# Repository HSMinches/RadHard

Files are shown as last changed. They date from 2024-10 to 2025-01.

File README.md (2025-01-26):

# RadHard
Radiation Hardened Voltage Regulation

Setup inicial de testes em um regulador compensado contra radiação e drifts de temperatura.

O tema central deste trabalho é o desenvolvimento de "Reguladores de tensão lineares para aplicações de baixo ruído em ambientes hostis", uma questão alinhada aos desafios enfrentados em setores críticos, como o aeroespacial e nuclear. Nesses contextos, os sistemas eletrônicos estão frequentemente sujeitos a variações extremas de temperatura e altos níveis de radiação, fatores que podem causar falhas graves, como Efeitos de Evento Único (SEE) e Danos Acumulados de Radiação (TID). Essas condições afetam diretamente o desempenho e a confiabilidade dos circuitos eletrônicos, especialmente em aplicações que exigem alta precisão e baixo ruído.

A escolha pelos reguladores de tensão lineares se justifica por sua capacidade de fornecer uma tensão de saída estável e limpa, essencial para circuitos sensíveis que necessitam de baixo ruído. Embora esses reguladores possam ser menos eficientes do que os modelos chaveados, sua baixa emissão de ruído os torna a opção mais adequada para sistemas de instrumentação e outros dispositivos que requerem alta estabilidade e precisão.

O objetivo deste projeto é desenvolver um regulador linear discreto, capaz de operar de forma eficiente em meio a grandes variações de temperatura e consideráveis níveis de exposição à radiação, evitando que essas condições provoquem alterações na tensão de saída, problema comum em ambientes hostis.

A imagem abaixo é referente a placa principal de regulação de tensão.



Data Flow Diagram Whiteboard in Dark Yellow Light Yellow Black Monochromatic Style(1)

Explicação dos blocos do diagrama: 

* Controle: bloco responsável pelo controle de toda a fonte, controlando a tensão e a corrente e pode desligar a fonte caso condições adversas aconteçam. Ele está localizado no meio da placa. 
* Temperatura: responsável pela medição de temperatura interna da placa. Tem ligação direta ao controle. A direita do bloco de radiação.
* Radiação: responsável pela medição de radiação incidida sobre o dispositivo. Se encontra no canto esquerdo inferior. 
* Referência: como o próprio nome já diz, é uma referência sobre a tensão estável do circuito. Canto superior esquerdo da placa.
* Proteção: protege contra sobretensão, transientes indesejados, proteção contra polaridade reversa e surtos de corrente. Está distribuído por toda a placa.
* Elemento de potência: São os elementos responsáveis por regular a tensão e suportar a maior carga de potência indesejado. Localizado na parte de trás da placa.



O bloco de controle é composto pelos componentes localizados no centro da placa, possui OP-AMPS e resistores de alta precisão e baixo drift térmico. 

# TESTES REALIZADOS

Após realizar o assembly dos componentes na PCB desenvolvida, foram realizados os seguintes testes para comprovar resultados iniciais utilizando o seguinte setup de testes:

setup1

O setup consiste de uma fonte auxiliar para gerar a alimentação negativa do circuito, um multímetro de 7 1/2 dígitos controlado por GPIB, uma fonte de sistema para alimentar a entrada da placa e a tensão auxiliar positiva da placa, um ADALM2000 para capturar dados de teste do LTPA (" Linear Technology Power Analyzer "), e uma probe de corrente que atua também como uma carga ativa na saída do circuito.  

Os seguintes resultados foram obtidos:

* Estabilidade de tensão:

Utilizando o multímetro de precisão em ambiente com temperatura controlada, foram adquiridas amostras durante várias horas em 2 níveis de tensão diferentes para avaliar a estabilidade do sistema. Como as figuras abaixo mostram:

5VREF_FILTERED

7VREF

Podendo obter bons resultados e com boa estabilidade em geral com os resultados medidos. 

* Transiente de cargas e ripple de regulação:

Foi utilizado o ADALM2000 e o LTPA em conjunto com a probe de corrente para gerar uma corrente de carga na saída do DUT, analisando assim a resposta de saída do sistema.

LTPA

Como demonstrado, existe um ripple extremamente baixo, mesmo com um transiente de carga rápido. Para cargas prolongadas, será necessário desenvolver uma solução térmica apropriada para o DUT.

* Teste de sobretemperatura:

Para evitar o stress dos componentes da placa, foi utilizado um soprador térmico em 100C para levar o sistema a falha de sobretemperatura, como este utiliza um disparador Schmitt, o sistema volta a funcionar automáticamente após a temperatura estabilizar em um nível aceitável novamente. No caso de falha, o sistema sai do indicador verde para o indicador laranja. 

https://github.com/user-attachments/assets/5670507f-7ce3-459a-abeb-b3ff87b2f2d7

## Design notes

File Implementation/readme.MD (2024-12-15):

INTRODUÇÃO                      
  O nosso projeto visa desenvolver e demonstrar o funcionamento de um regulador de tensão e corrente projetado para operar em ambientes extremos, com variações de temperaturas e exposição à radiação. O projeto é voltado para aplicações em setores como aeroespacial, indústria nuclear e setor militar, onde a robustez e a confiabilidade são fundamentais. 

OBJETIVO                  
  O principal objetivo do projeto é desenvolver um regulador de tensão e corrente capaz de:        
● Operar em temperaturas que variam de 0°C a 60°C ou mais.          
● Resistir a doses elevadas de radiação ionizante sem comprometer a funcionalidade.         
● Fornecer tensões e correntes estáveis em condições adversas.                   
● Garantir durabilidade e confiabilidade mesmo em ciclos térmicos prolongados e sob exposição à radiação.         
● A regulação de tensão e corrente se dá por malhas de feedback analógico. Sua tensão máxima de saída gira em torno de 14V, já a máxima corrente de saída, podemos afirmar que gira em torno de 1A.

MATERIAIS              
  A seleção dos materiais foi baseada em técnicas de compensação térmica e técnicas de design contra falhas induzidas por radiação, levando como base desempenho por custo benefício. Ademais todos os componentes deste projeto foram adquiridos de forma gratuita. Contudo se fossemos fazer uma estimativa de custo para esse projeto, o valor total estaria próximo de $2000 USD.

TESTES FUTUROS               
  O protótipo será submetido a uma série de testes para validar seu desempenho e durabilidade:    
● HASS (Highly Accelerated Stress Screening): O regulador será colocado em câmaras climáticas para avaliar seu funcionamento em condições de calor e frio.     
● Exposição à Radiação: Ensaios com feixes de íons pesados e fontes de radiação irão simular condições espaciais e ambientes nucleares.       
● HALT (Highly Accelerated Life Test) : O dispositivo irá ser submetido a ciclos repetidos de aquecimento e resfriamento para verificar sua resistência à fadiga térmica.   

CONCLUSÃO                  
      O regulador desenvolvido tende a ter desempenho satisfatório, operando de forma aceitável em variações de temperaturas e sob exposição a doses de radiação. Com base em especificações de componentes obtidas em bancos de dados, o dispositivo estaria apto para aplicações em ambientes adversos, como indústria aeroespacial, indústria nuclear e determinados usos militares. O sucesso deste projeto reforça a viabilidade do uso de componentes COTS (Commercial-Off-The-Shelf) e estratégias de design tolerantes a condições adversas.

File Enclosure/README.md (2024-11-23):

A case que irá envolver a placa foi desenvolvida utilizando o software Inventor e será fabricada em alumínio, um material conhecido por sua resistência e leveza. O principal objetivo dessa case é fornecer uma proteção robusta para a placa e seus componentes, evitando danos mecânicos, poeira e outras interferências externas que poderiam comprometer seu funcionamento. Além disso, o uso de alumínio contribui para a dissipação de calor, ajudando a manter os componentes em uma temperatura ideal e prolongando a vida útil do equipamento.

Montagem1

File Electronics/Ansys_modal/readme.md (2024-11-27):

Análise modal até a oitava ordem : 

ModalAnalysis

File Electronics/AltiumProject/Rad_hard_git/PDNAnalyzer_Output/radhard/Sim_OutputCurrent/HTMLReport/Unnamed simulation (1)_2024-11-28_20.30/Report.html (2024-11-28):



PDN Analyzer Results Report for
radhard

PDN Analyzer Version: 2.0.42.524
Report Time / Date: 11/28/2024 8:30:09 PM
Project Name: radhard
Project Path: C:\Users\Public\Documents\Altium\Projects\RAD_GIT\RadHard\Electronics\AltiumProject\Rad_hard_git\radhard.PcbDoc
PCB Design Name: radhard.PcbDoc
PDN Analyzer Configuration File: C:\Users\Public\Documents\Altium\Projects\RAD_GIT\RadHard\Electronics\AltiumProject\Rad_hard_git\PDNAnalyzer_Output\radhard\Unnamed simulation (1)\HTMLReport\Unnamed simulation (1)_2024-11-28_20.30\Unnamed simulation (1).pdna

Design Stackup

Layer Name | Layer Name | Material | Thickness (mm) | Dielectric Material | Dielectric Constant | Pullback (mm) | Orientation
Top Overlay | Overlay | | | | | | Top
Top Solder | Solder Mask | Surface Material | 0.0254 | SM-001 | 4 | | Top
Top Layer | Signal | Copper | 0.035 | | | | Top
Dielectric 1 | Dielectric | Prepreg | 0.07112 | PP-006 | 4.1
Dielectric 2 | Dielectric | Prepreg | 0.07112 | PP-006 | 4.1
Int1 (GND) | Internal | Copper | 0.035 | | | 0.508
Dielectric 3 | Dielectric | Core | 0.4572 | Core-035 | 4.7
Int2 (Sign) | Signal | Copper | 0.035
Dielectric 4 | Dielectric | Prepreg | 0.07112 | PP-006 | 4.1
Dielectric 5 | Dielectric | Prepreg | 0.07112 | PP-006 | 4.1
Int3 (Sign) | Signal | Copper | 0.035
Dielectric 6 | Dielectric | Core | 0.4572 | Core-035 | 4.7
Int4 (PWR) | Internal | Copper | 0.035 | | | 0.508
Dielectric 7 | Dielectric | Prepreg | 0.07112 | PP-006 | 4.1
Dielectric 8 | Dielectric | Prepreg | 0.07112 | PP-006 | 4.1
Bottom Layer | Signal | Copper | 0.035 | | | | Bottom
Bottom Solder | Solder Mask | Surface Material | 0.0254 | SM-001 | 4 | | Bottom
Bottom Overlay | Overlay | | | | | | Bottom

Artwork by Layer

Layer: Top Layer
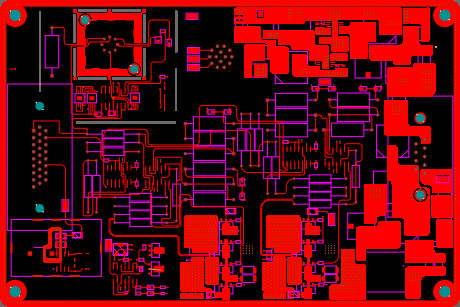
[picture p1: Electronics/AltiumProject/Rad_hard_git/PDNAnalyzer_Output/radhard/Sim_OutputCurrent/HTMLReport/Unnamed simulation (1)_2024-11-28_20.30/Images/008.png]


Layer: Int1 (GND)
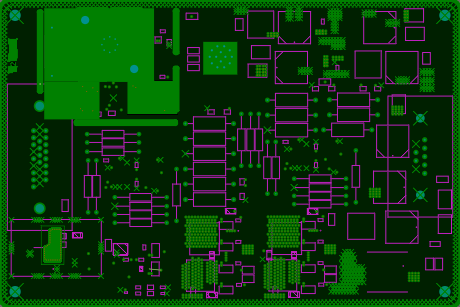
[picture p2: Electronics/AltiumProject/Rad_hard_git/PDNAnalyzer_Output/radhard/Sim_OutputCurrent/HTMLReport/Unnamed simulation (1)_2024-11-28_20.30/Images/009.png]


Layer: Int2 (Sign)
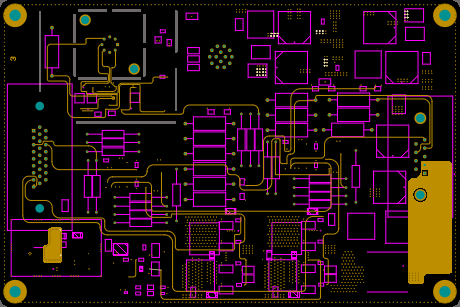
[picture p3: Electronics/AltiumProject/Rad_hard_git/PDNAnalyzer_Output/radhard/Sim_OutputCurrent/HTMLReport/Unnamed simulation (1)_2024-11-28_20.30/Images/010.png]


Layer: Bottom Layer
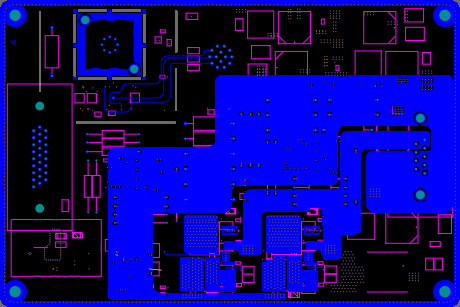
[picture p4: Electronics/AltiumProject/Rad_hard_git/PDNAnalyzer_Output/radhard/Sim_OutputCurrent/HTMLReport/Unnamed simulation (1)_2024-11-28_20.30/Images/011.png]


PDN Analizer Global Settings

Parameter | Value
Metal conductivity | 47M S/m
Metal base temperature | 3E+01 °C
Metal work temperature | 3E+01 °C
Metal base conductivity | 47M S/m
Metal temperature coefficient | 4E+02m %/°C
Conductor Max Current Density for Surfase Layers | 0 A/mm^2
Conductor Max Current Density for Internal Layers | 0 A/mm^2
Via wall thickness | 17.78 μm
Max Via Current Density | 0 A/mm^2

System-Level Power Network Results

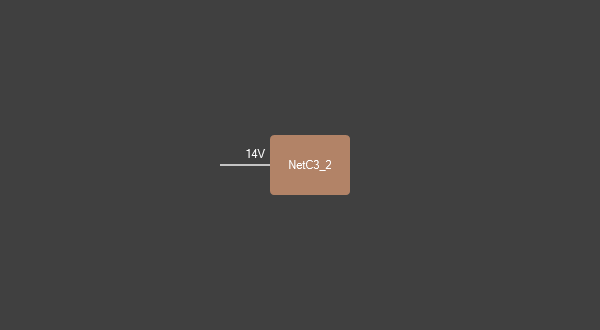
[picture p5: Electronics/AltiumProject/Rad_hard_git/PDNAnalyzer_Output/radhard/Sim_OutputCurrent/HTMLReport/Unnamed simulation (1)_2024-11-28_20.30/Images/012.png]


Simulation Pass/Fail Overall: PASS
NetC3_2 PASS

Total Power Consumption: 56 Watts

Figure <1>: Probe 003 Screenshot

13.97 V on Layer: BOTTOM_LAYER Net: NETC3_2 Coordinates: 163.060 : 80.315

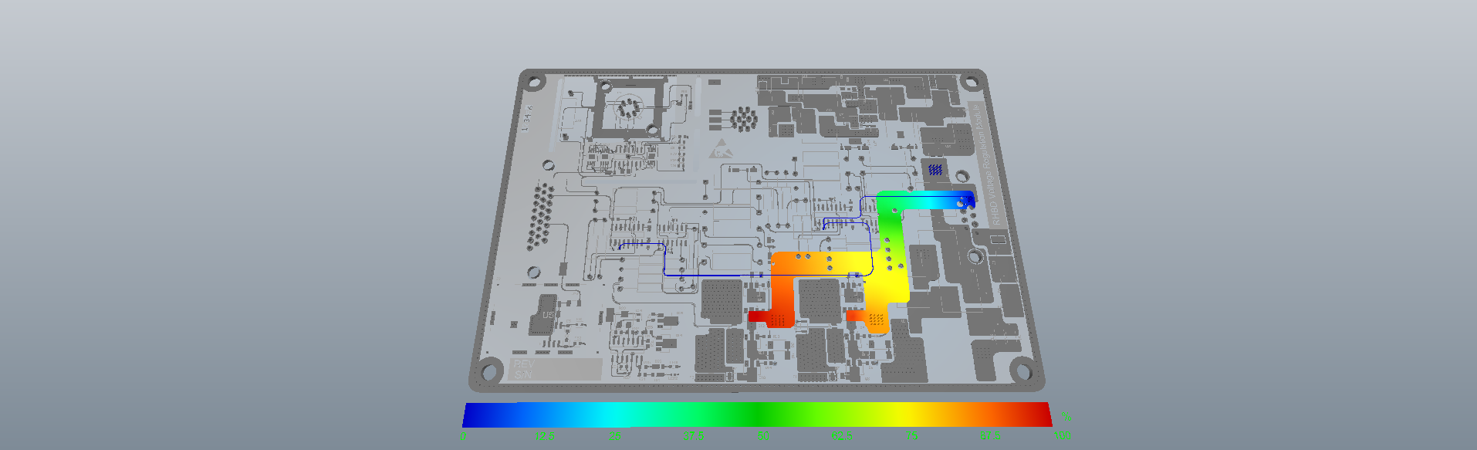
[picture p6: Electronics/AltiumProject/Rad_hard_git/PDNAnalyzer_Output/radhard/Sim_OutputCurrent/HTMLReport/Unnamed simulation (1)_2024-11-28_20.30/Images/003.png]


Figure <2>: Probe 002 Screenshot

13.97 V on Layer: BOTTOM_LAYER Net: NETC3_2 Coordinates: 163.060 : 80.315

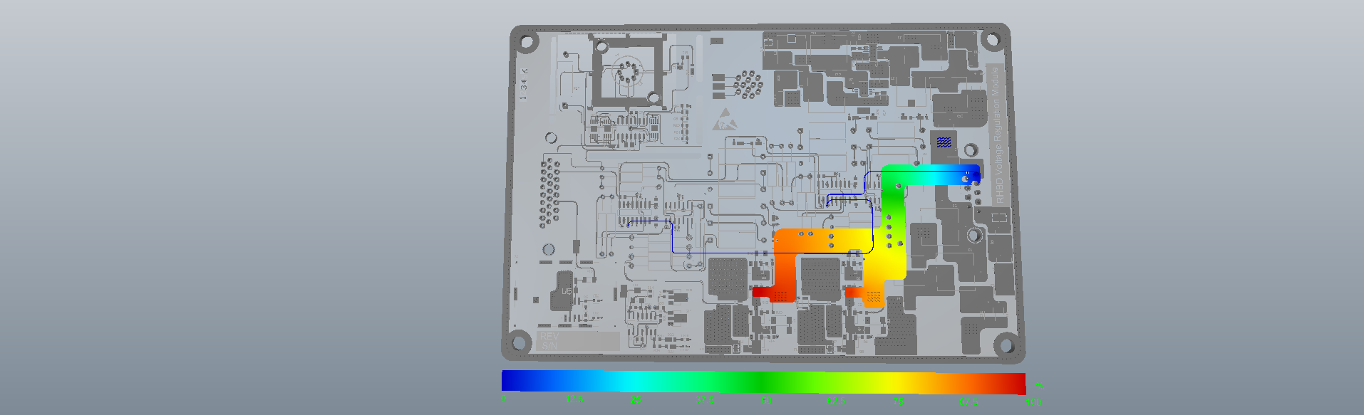
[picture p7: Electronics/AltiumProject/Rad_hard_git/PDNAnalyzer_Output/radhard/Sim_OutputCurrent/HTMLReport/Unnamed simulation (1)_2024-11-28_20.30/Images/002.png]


Figure <3>: Screenshot 004

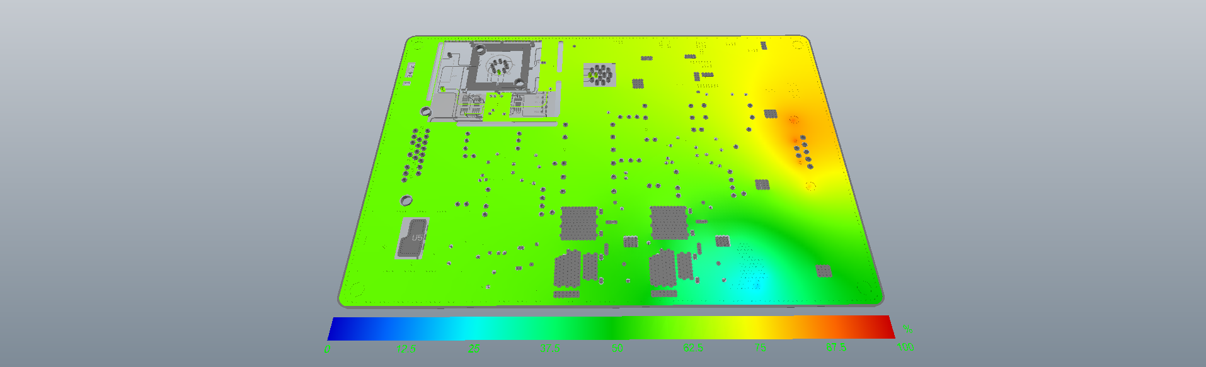
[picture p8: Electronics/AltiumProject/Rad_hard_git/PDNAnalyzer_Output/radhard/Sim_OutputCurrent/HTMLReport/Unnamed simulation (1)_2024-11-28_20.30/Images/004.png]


Figure <4>: Screenshot 005

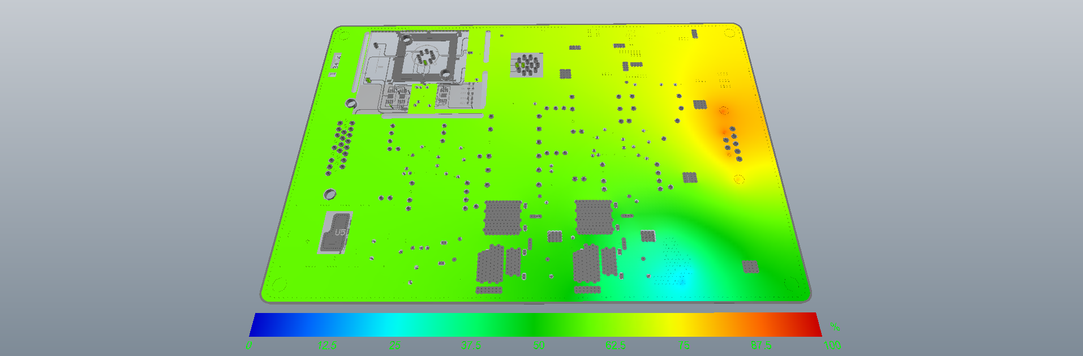
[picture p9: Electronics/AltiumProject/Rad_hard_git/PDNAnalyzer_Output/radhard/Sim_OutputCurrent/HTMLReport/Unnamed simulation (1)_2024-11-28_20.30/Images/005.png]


Figure <5>: Screenshot 006

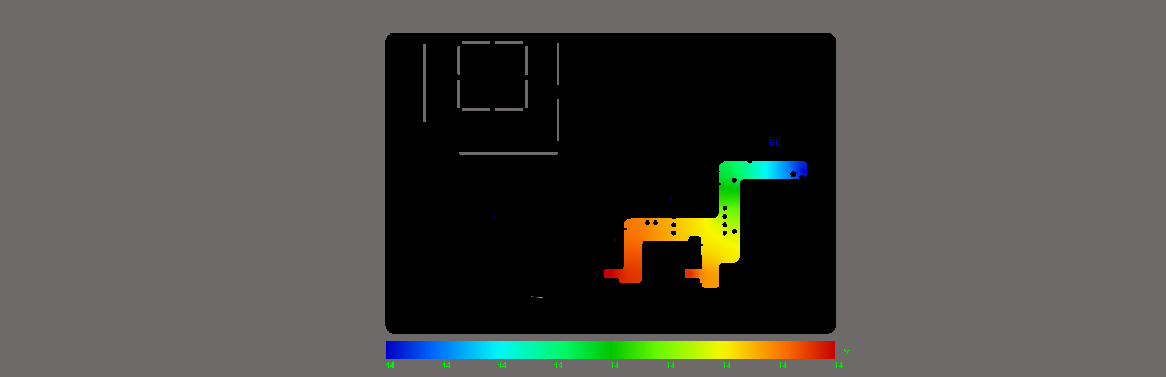
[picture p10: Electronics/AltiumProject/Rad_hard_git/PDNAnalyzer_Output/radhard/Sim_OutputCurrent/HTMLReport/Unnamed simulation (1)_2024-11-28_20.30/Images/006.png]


Figure <6>: Screenshot 007

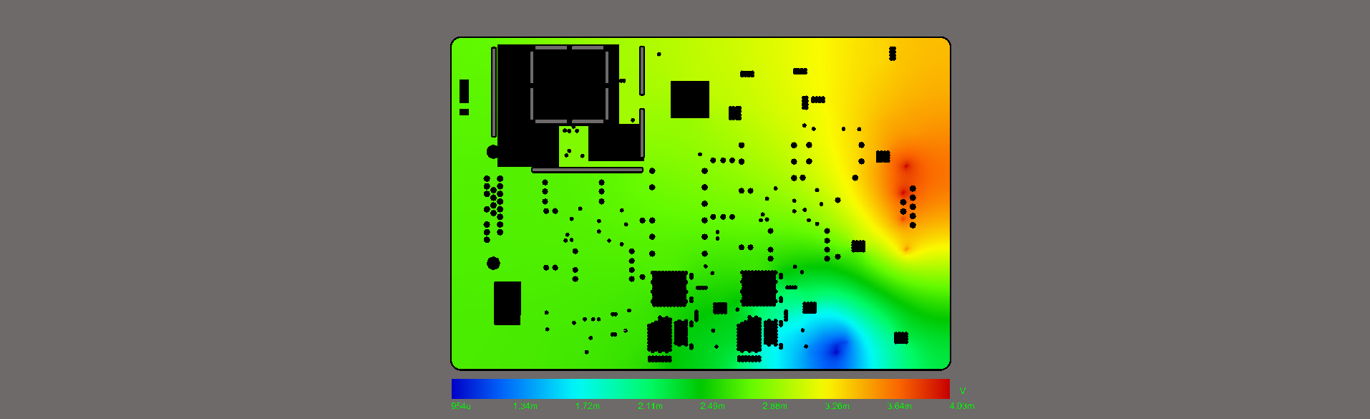
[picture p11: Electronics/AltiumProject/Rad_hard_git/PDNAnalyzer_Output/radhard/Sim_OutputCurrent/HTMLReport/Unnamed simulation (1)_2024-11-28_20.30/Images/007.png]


Network NetC3_2 Details

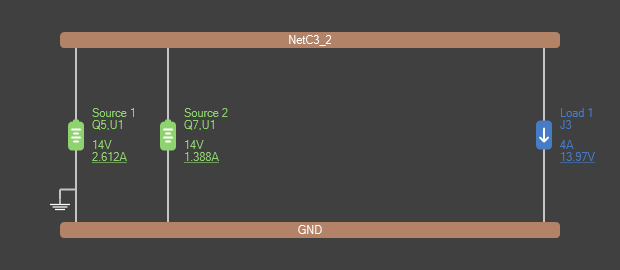
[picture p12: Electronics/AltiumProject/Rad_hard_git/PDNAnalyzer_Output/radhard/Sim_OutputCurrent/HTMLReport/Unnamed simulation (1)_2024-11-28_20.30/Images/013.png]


PDN Analysis Pass/Fail: PASS

Power Consumption for This Network: 56 Watts

Voltage Source Performance Summary:

ID | Source Type | Ref Des | Pass / Fail | Vout setting (V) | Actual Output Voltage (V) | Max Output Current (A) | Actual Output Current (A) | Margin (A) | Margin (%) | Max Pin Current | Highest Actual (A) | Margin (A) | Margin (%) | Max Power Dissipation (W) | Actual Power Dissipation (W) | Margin (W) | Margin (%)
Source 1 | Voltage Source | Q5, U1 | PASS | 14 | 13.997 | 0 | 2.6118 | ∞ | ∞ | 0 | 2.6118 | ∞ | ∞
Source 2 | Voltage Source | Q7, U1 | PASS | 14 | 13.999 | 0 | 1.3882 | ∞ | ∞ | 0 | 1.3882 | ∞ | ∞

Voltage Source Pin Voltage/Current Details:

ID | SourceType | Terminal | Ref Des | Pin | Max Pin Current (A) | Actual Pin Current (A) | Pass / Fail | Pin Voltage (V)
Source 1 | Voltage Source | Power | Q5 | 3 | 0 | 2.6118 | PASS | 13.997
Source 1 | Voltage Source | Ground | U1 | 4 | 0 | 2.6118 | PASS | 0
Source 2 | Voltage Source | Power | Q7 | 3 | 0 | 1.3882 | PASS | 13.999
Source 2 | Voltage Source | Ground | U1 | 4 | 0 | 1.3882 | PASS | 0

Load Performance Summary:

ID | Load Type | Ref Des | Pass / Fail | Load Value | Min Voltage (V) | Max Voltage (V) | Actual Voltage | Margin (V) | Margin (%) | Min Pwr Pin | Voltage (V) | Max Gnd Pin | Voltage (V) | Actual Current (A)
Load 1 | Current | J3 | PASS | 4A | 0 | 0 | 13.969 | 0 | ∞ | J3-5 | 13.973 | J3-9 | 4.5406m | 4

Load Pin Voltage/Current Details:

ID | Load Type | Terminal | Ref Des | Pin | Pin Voltage (V) | Pin Current (A)
Load 1 | Current | Power | J3 | 5 | 13.973 | 4
Load 1 | Current | Ground | J3 | 9 | 4.5406m | 991.65m
Load 1 | Current | Ground | J3 | 6 | 4.3348m | 996.8m
Load 1 | Current | Ground | J3 | SH2 | 4.1907m | 1.0004
Load 1 | Current | Ground | J3 | SH1 | 3.7606m | 1.0112

Component Definition Summary:

ID | Ref Des | Type | In+ Pins | In- Pins | Out+ Pins | Out- Pins | S+ | S- | Vout (V) | Efficiency (%) | Ibias (A) | Resistance | Load Current (A) | Vmin | Vmax | Iout max (A) | PD max (W) | Pin Current max (A)
Source 1 | Q5, U1 | Voltage Source | | | Q5-3 | U1-4 | | | 14 | | | | | | | 0 | | 2.6118
Source 2 | Q7, U1 | Voltage Source | | | Q7-3 | U1-4 | | | 14 | | | | | | | 0 | | 1.3882
Load 1 | J3 | Current | J3-5 | J3-9,6,SH2,SH1 | | | | | | | | | 4 | 0 | 0

## Figure <7>: Screenshot 001

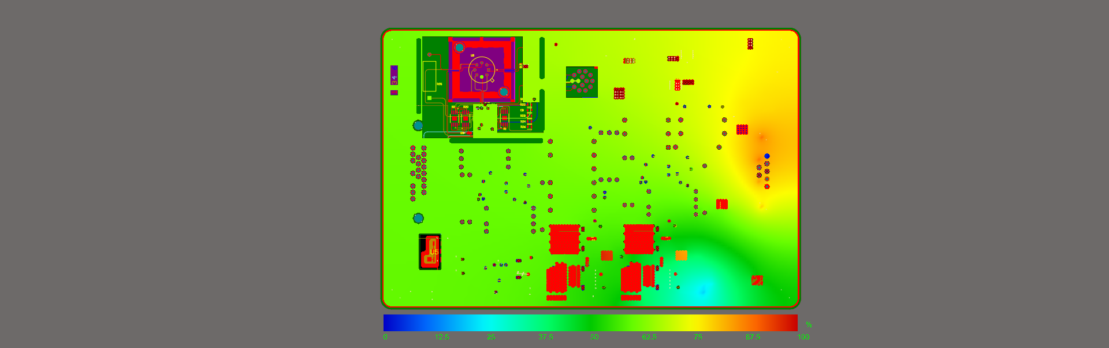
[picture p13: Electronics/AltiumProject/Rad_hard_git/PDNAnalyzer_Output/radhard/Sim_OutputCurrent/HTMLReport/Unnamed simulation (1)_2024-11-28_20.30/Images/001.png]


Network Simulation Messages Details

Type | Text
Info | Generated the settings file: C:\Users\Public\Documents\Altium\Projects\RAD_GIT\RadHard\Electronics\AltiumProject\Rad_hard_git\PDNAnalyzer_Output\radhard\Unnamed simulation (1)\radhard.py
Info | Load and analyze result for Unnamed simulation (1)
Info | No violations
Info | Analysis Complete Unnamed simulation (1)

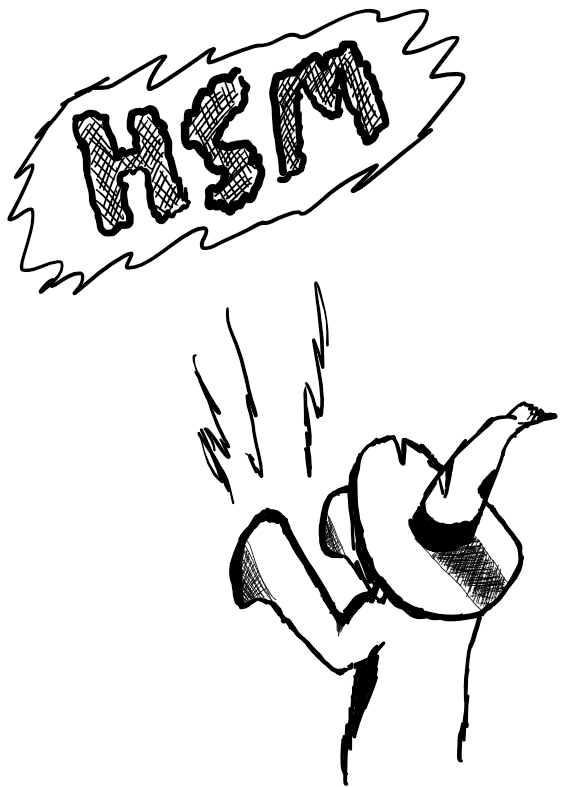
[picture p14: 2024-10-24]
Electronics/AltiumProject/Rad_hard_git/IMG/magesketch.bmp

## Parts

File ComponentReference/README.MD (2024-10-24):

Reference links for radiation tested components: 

-https://esarad.esa.int/
-https://radhome.gsfc.nasa.gov/radhome/RadDataBase/RadDataBase.html

Reference for significative test data interpretation:

-https://radhome.gsfc.nasa.gov/radhome/RadDataBase/RadDataBase.html

External design references: 

Josemary A.C. Gonçalves, Alessio Mangiarotti, Carmen C. Bueno,
Characterization of a thin photodiode as a routine dosimeter for low-dose radiation processing applications,
Radiation Physics and Chemistry,
Volume 198,
2022,
110200,
ISSN 0969-806X,

P. C. Adell and L. Z. Scheick, "Radiation Effects in Power Systems: A Review," in IEEE Transactions on Nuclear Science, vol. 60, no. 3, pp. 1929-1952, June 2013, doi: 10.1109/TNS.2013.2262235.
keywords: {Voltage control;Regulators;Topology;Radiation effects;Switches;Switching converters;Mathematical model;DC-DC converters;digital control;linear regulators;power systems;single event effects;total dose}

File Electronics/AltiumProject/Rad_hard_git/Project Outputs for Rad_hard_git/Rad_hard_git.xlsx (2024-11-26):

Comment | Description | Designator | Footprint | LibRef | Quantity
Component_1 |  | Amph | PCBComponent_1 | ACRK-16-01-G-T-B1-M-1 | 1
MAL214099801E3 | No Description Available | C1, C2, C3, C10, C11, C12, C13 | CAP_140CRH_1010_VIS | MAL214099801E3 | 7
12065A5R6DAT2A | CAP CER 5.6PF 50V C0G/NP0 1206 | C4 | CAPC3216X94N | 12065A5R6DAT2A | 1
CC0603KRX7R7BB105 | CAP CER 1UF 16V X7R 0603 | C5, C6, C14, C15, C16 | FP-CC0603-DA-MFG | CMP-03422-000924-1 | 5
06033C104KAT2A | General Purpose Ceramic Capacitor, 0603, 100nF, 10%, X7R, 15%, 25V | C7, C8 | FP-0603-L_1_6_0_15-W_0_81-MFG | CMP-2006-04157-2 | 2
VJ0805Y223KXXAC |  | C9 | CAPC2012X145N | VJ0805Y223KXXAC | 1
GRM31CR71E106KA12L | Chip Multilayer Ceramic Capacitors for General Purpose, 1206, 10uF, X7R, 15%, 10%, 25V | C17, C18, C19, C20 | FP-GRM31C-0_2-e0_3_0_8-MFG | CMP-06035-003589-1 | 4
CC0402KRX7R9BB104 | CAP CER 0.1UF 50V X7R 0402 | C21_Temperature_Enhanced_WB1, C21_Temperature_Enhanced_WB2, C22_Temperature_Enhanced_WB1, C22_Temperature_Enhanced_WB2, C23_Temperature_Enhanced_WB1, C23_Temperature_Enhanced_WB2 | FP-CC0402-MFG | CMP-03422-001010-1 | 6
PTVS12VP1UP,115 | Diode ESD (Uni-directional) | D1, D2, D5, D6, D11, D12, D17, D18 | PMEG3050EP115 | PTVS12VP1UP,115 | 8
YQ15RSM10SDTL1 | Schottky Diode | D3, D4, D7, D15, D16, D19, D20 | YQ15RSM10SDTL1 | YQ15RSM10SDTL1 | 7
VBPW34S | VBPW34SR Series 60 V 940 nm 50 mA 215 mW Surface Mount Silicon PIN Photodiode | D8 | XDCR_VBPW34S | VBPW34S | 1
RF05VYM1SFHTR | Diode | D9, D10, D21, D22, D23_Temperature_Enhanced_WB1, D23_Temperature_Enhanced_WB2, D24_Temperature_Enhanced_WB1, D24_Temperature_Enhanced_WB2, D25_Temperature_Enhanced_WB1, D25_Temperature_Enhanced_WB2, D26_Temperature_Enhanced_WB1, D26_Temperature_Enhanced_WB2 | RF05VYM1SFHTR | RF05VYM1SFHTR | 12
0483005.DR | Fuse | F1, F3 | FUSC3316X137N | 0483005.DR | 2
0483010.DR | Fuse | F2 | FUSC3316X137N | 0483010.DR | 1
MH1608-601Y | FERRITE BEAD 600 OHM 0603 1LN | FB1, FB2 | FP-MH1608-MFG | CMP-2000-06698-2 | 2
GUARD_RING |  | GR | Guard | Component_1 | 1
MDBRA26PEAN0 | Connector | J1 | MDBRA26PEAN0 | MDBRA26PEAN0 | 1
2118728-2 |  | J2 | TE_2118728-2 | 2118728-2 | 1
MDBRE09PE860 |  | J3 | AMPHENOL_MDBRE09PE860 | MDBRE09PE860 | 1
SER8052-402MEC | Inductor | L1, L2, L3 | SER8052402MEC | SER8052-402MEC | 3
SMLD12EN1WT86C | LED | LED1 | SMLD12EN1WT86C | SMLD12EN1WT86C | 1
SML-P11DTT86R | LED | LED2 | SML-P11(1X0.6) | SML-P11DTT86R | 1
UJ4SC075018B7S | MOSFET 750V/18mO,SICFET,G4,TO263-7 | Q1, Q6 | UJ4SC075018B7S | UJ4SC075018B7S | 2
2SD1834T100 | Transistor BJT NPN | Q2, Q3, Q4, Q8, Q9, Q10, Q11, Q12, Q14, Q15 | RJP020N06 | 2SD1834T100 | 10
IXTA6N100D2 | N-Channel 1000 V 6 A 2.2 Ohm SMT Depletion Mode Power Mosfet - D2PAK | Q5, Q7 | DPAK254P1524X483-3N | IXTA6N100D2 | 2
2SCR563F3TR | Transistor BJT NPN | Q13 | 2SAR542F3 | 2SCR563F3TR | 1
LT5400ACMS8E-3#PBF | 1k, 9k Ohm Â±15% 800mW Power Per Element Isolated Resistor Network/Array Â±25ppm/Â°C 8-TSSOP, 8-MSOP (0.118", 3.00mm Width) Exposed Pad | R1, R20 | SOP65P490X110-9N | LT5400ACMS8E-3#PBF | 2
LT5400BHMS8E-8#TRPBF | 1k, 9k Ohm Â±15% 800mW Power Per Element Isolated Resistor Network/Array Â±25ppm/Â°C 8-TSSOP, 8-MSOP (0.118", 3.00mm Width) Exposed Pad | R2 | SOP65P490X110-9N | LT5400BHMS8E-8#TRPBF | 1
WSLP0805R0100FEA |  | R3, R9 | RESC2013X58X38LL25T25 | CMP-2001-04321-1 | 2
ERA8AEB124V |  | R4, R7, R10, R11 | RESC3216X70X50LL20T25 | CMP-2003-04417-1 | 4
MCT06030C1001FP500 | Res Thin Film 0603 1K Ohm 1% 0.1W(1/10W) ?50ppm/C Molded SMD Automotive Medical T/R | R5, R6, R8, R12, R13, R14, R15, R17, R19, R21, R30, R34, R35, R50_Temperature_Enhanced_WB1, R50_Temperature_Enhanced_WB2, R53_Temperature_Enhanced_WB1, R53_Temperature_Enhanced_WB2, R54_Temperature_Enhanced_WB1, R54_Temperature_Enhanced_WB2, R55, R56 | RESC1508X55N | MCT06030C1001FP500 | 21
ERJ-8GEYJ241V |  | R16 | RESC3216X70X50NL05T20 | CMP-2003-00592-1 | 1
CRHP1206AF1G00FKET | No Description Available | R18 | RES_CRHP1206_VIS | CRHP1206AF1G00FKET | 1
MCT06030C1004FPW00 | RES SMD 100 OHM 1% 1/8W 0603 | R22, R23, R24, R26 | FP-MCT0603-MFG | CMP-02407-007592-1 | 4
UPF50B100RV | No Description Available | R25 | RES_UPF50B2K0V_TEC | UPF50B100RV | 1
0402WGF1000TCE | Resistor | R27 | RESC1005X40N | 0402WGF1000TCE | 1
TNPW0603120KBEEA |  | R28, R29 | RESC1508X55N | TNPW0603120KBEEA | 2
TNPW060310K0BEEA |  | R31 | RESC1609X55X30NL10T20 | CMP-2000-03691-1 | 1
PTS1206M2B1K00P100 | No Description Available | R32 | PTS 1206_VIS | PTS1206M2B1K00P100 | 1
3214W-1-502E | 3214 - 5-Turn Trimpot(R) Trimming Potentiometer, 5 KOhm, +/- 10%, 0.25 W, -65 to 150 degC, RoHS, Tape and Reel | R33 | BOUR-3214W_V | CMP-2000-05579-1 | 1
H810KBYA | Resistor | R36_Temperature_Enhanced_WB1, R36_Temperature_Enhanced_WB2, R37_Temperature_Enhanced_WB1, R37_Temperature_Enhanced_WB2 | RESAD1690W60L710D245 | H810KBYA | 4
H81M0BYA | Resistor | R38_Temperature_Enhanced_WB1, R38_Temperature_Enhanced_WB2, R39_Temperature_Enhanced_WB1, R39_Temperature_Enhanced_WB2 | RESAD1690W60L710D245 | H810KBYA | 4
H81K0BYA | Resistor | R40_Temperature_Enhanced_WB1, R40_Temperature_Enhanced_WB2, R45_Temperature_Enhanced_WB1, R45_Temperature_Enhanced_WB2, R46_Temperature_Enhanced_WB1, R46_Temperature_Enhanced_WB2, R49_Temperature_Enhanced_WB1, R49_Temperature_Enhanced_WB2, R51_Temperature_Enhanced_WB1, R51_Temperature_Enhanced_WB2, R52_Temperature_Enhanced_WB1, R52_Temperature_Enhanced_WB2 | RESAD1690W60L710D245 | H810KBYA | 12
UPF50B100KV | No Description Available | R41_Temperature_Enhanced_WB1, R41_Temperature_Enhanced_WB2, R42_Temperature_Enhanced_WB1, R42_Temperature_Enhanced_WB2, R43_Temperature_Enhanced_WB1, R43_Temperature_Enhanced_WB2, R44_Temperature_Enhanced_WB1, R44_Temperature_Enhanced_WB2, R47_Temperature_Enhanced_WB1, R47_Temperature_Enhanced_WB2, R48_Temperature_Enhanced_WB1, R48_Temperature_Enhanced_WB2 | RES_UPF50B2K0V_TEC | UPF50B100RV | 12
5019 |  | TP1, TP2, TP3, TP9, TP10, TP11, TP13, TP16, TP17 | KEYSTONE_5019 | 5019 | 9
CH4659-ALD | No Description Available | U1 | CH4659-ALD_COC | CH4659-ALD | 1
LT3045EMSE#TRPBF | IC REG LINEAR 0V 500MA 12MSOP | U2 | FP-MSE-12-05-08-1666-IPC_B | CMP-09138-000053-1 | 1
LTZ1000ACH#PBF | IC VREF SHUNT 7.2V TO5 | U3 | FP-H-8-05-08-1320-MFG | CMP-09137-000002-1 | 1
ADA4522-4ARZ-RL | IC OPAMP ZERO-DRIFT 4CIRC 14SOIC | U4, U6_Temperature_Enhanced_WB1, U6_Temperature_Enhanced_WB2, U9 | FP-R-14-IPC_C | CMP-09116-000280-1 | 4
ADA4530-1ARZ |  | U5 | SOIC127P600X175-8N | ADA4530-1ARZ | 1
LT3094EMSE#PBF | IC REG LIN NEG ADJ 500MA 12MSOP | U7 | FP-MSE-12-05-08-1666-MFG | CMP-09138-000010-1 | 1
ADG452BRZ | IC SWITCH QUAD SPST 16SOIC | U8_Temperature_Enhanced_WB1, U8_Temperature_Enhanced_WB2 | FP-R-16-IPC_B | CMP-09113-000001-1 | 2

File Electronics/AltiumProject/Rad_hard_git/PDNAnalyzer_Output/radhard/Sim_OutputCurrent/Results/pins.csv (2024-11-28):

refdes | pin | voltage | current
Q5 | 3 | 13.9974 | 2.61184
U1 | 4 | 0.0 | -4.0
Q7 | 3 | 13.9986 | 1.38816
J3 | 5 | 13.9731 | -4.0
J3 | 9 | 0.00454064 | 0.991651
J3 | 6 | 0.00433479 | 0.996798
J3 | SH2 | 0.00419073 | 1.0004
J3 | SH1 | 0.00376062 | 1.01115

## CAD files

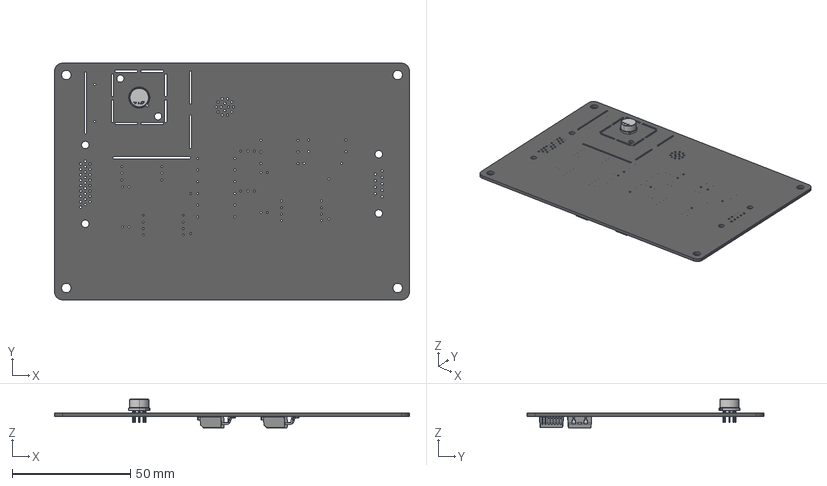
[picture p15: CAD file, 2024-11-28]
Electronics/AltiumProject/Rad_hard_git/radhard3.step
150.0 x 100.0 x 12.1 mm

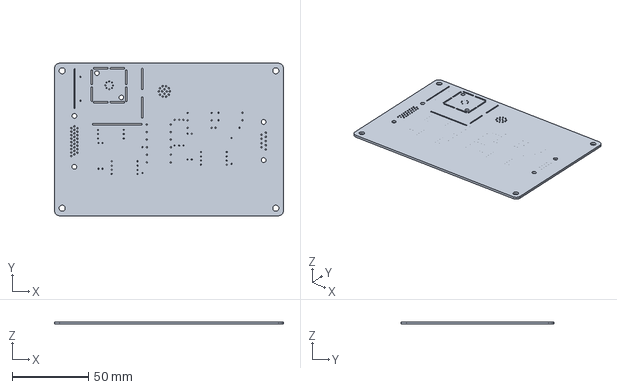
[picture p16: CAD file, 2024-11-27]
Electronics/AltiumProject/Rad_hard_git/radhard2.step
150.0 x 100.0 x 1.60 mm

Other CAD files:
Enclosure/peça pi2.ipt

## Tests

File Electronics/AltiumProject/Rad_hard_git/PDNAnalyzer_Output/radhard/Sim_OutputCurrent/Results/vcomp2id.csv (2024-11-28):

vrefdes | id
VCOMP0 | 0
VCOMP1 | 1
VCOMP2 | 2

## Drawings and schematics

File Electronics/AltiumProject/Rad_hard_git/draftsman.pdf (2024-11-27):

### D11 D⁶

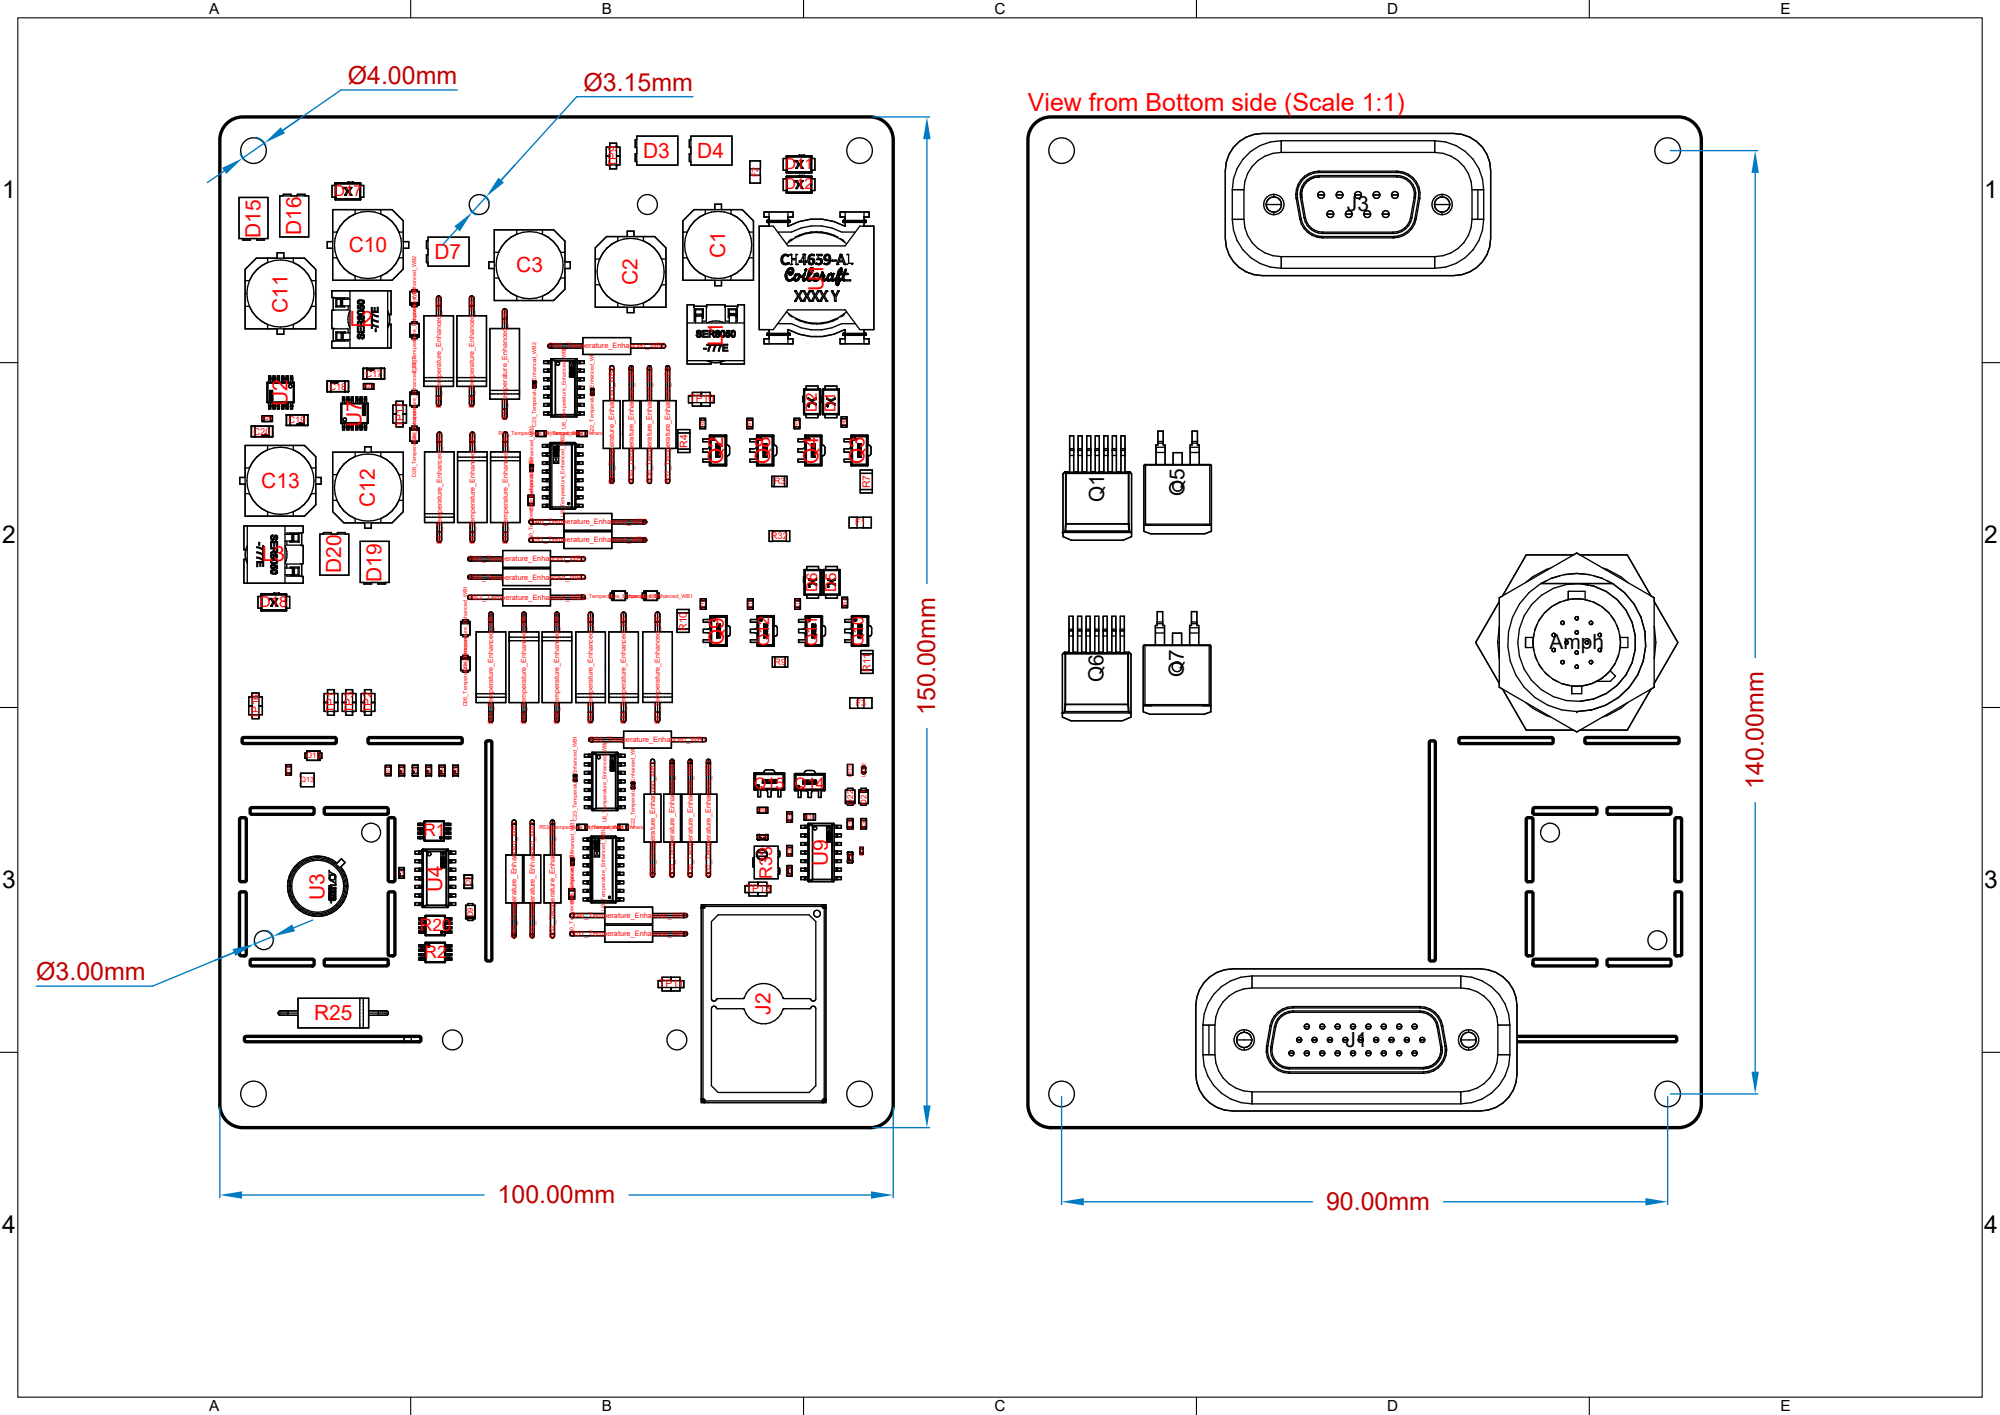
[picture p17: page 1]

View from Bottom side (Scale 1:1)

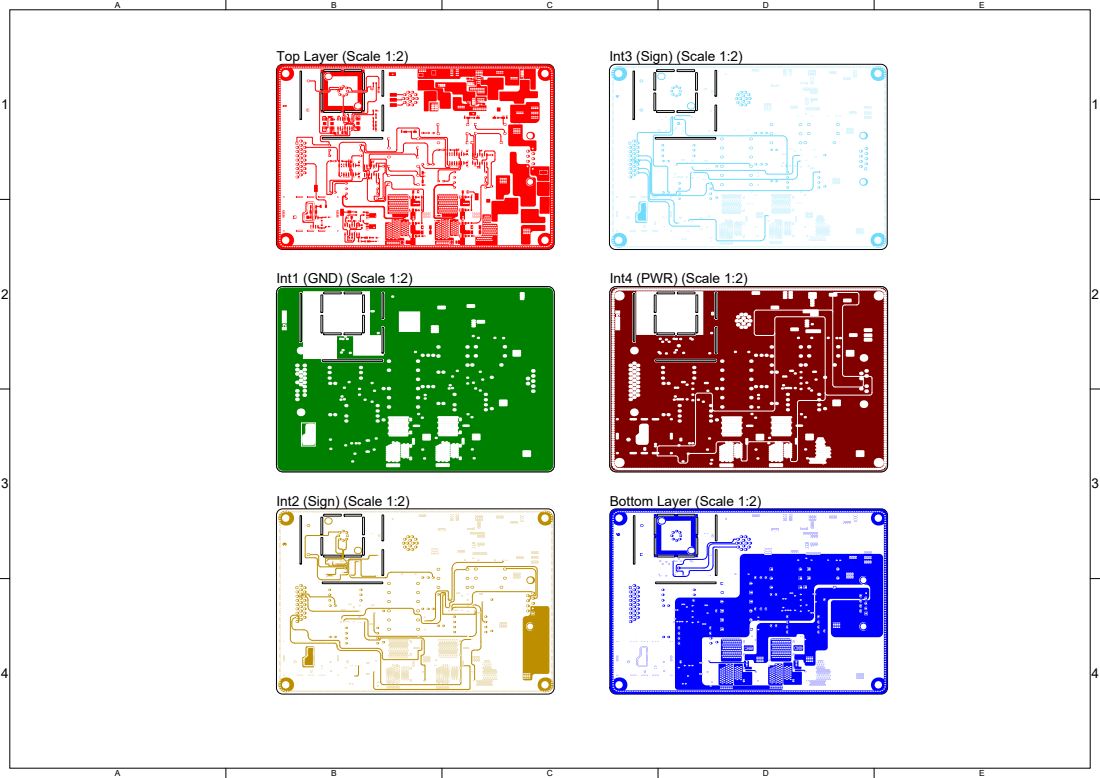
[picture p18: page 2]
Int1 (GND) (Scale 1:2); Int2 (Sign) (Scale 1:2); Int3 (Sign) (Scale 1:2); Int4 (PWR) (Scale 1:2)

Top Layer (Scale 1:2)

Bottom Layer (Scale 1:2)

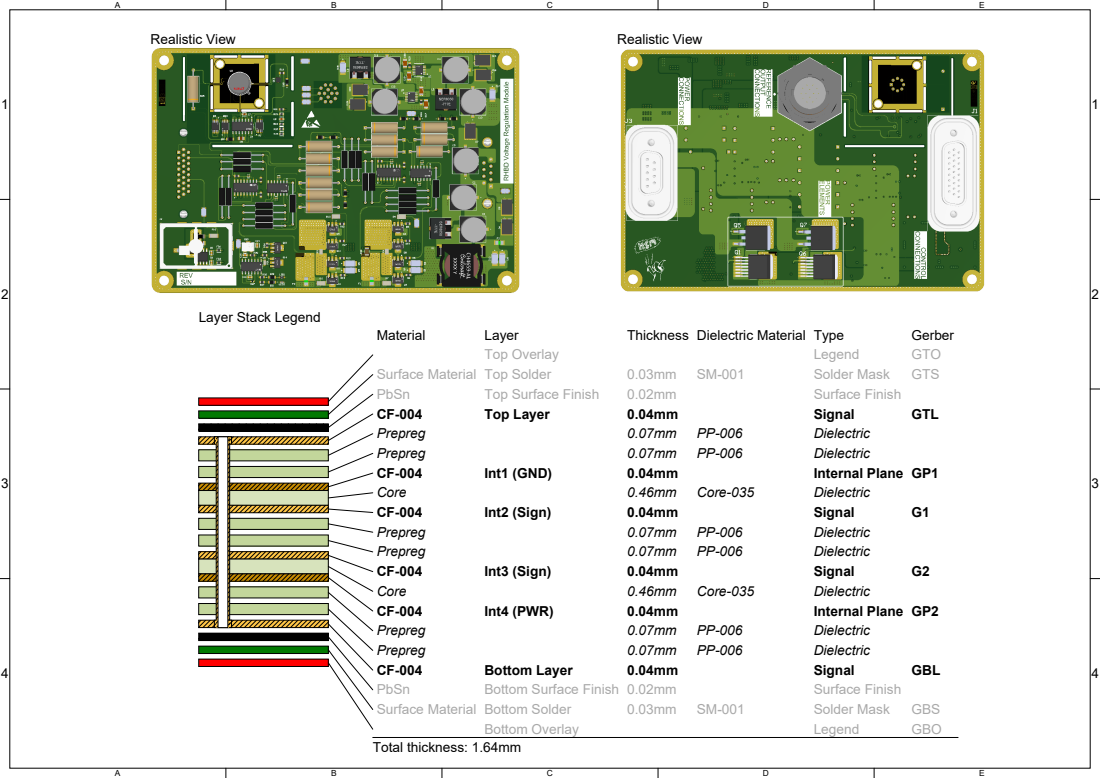
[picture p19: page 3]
Realistic View; Material; Layer; Thickness Dielectric Material Type; Gerber; Top Overlay; Legend; GTO; Surface Material Top Solder; Solder Mask; GTS; PbSn; Top Surface Finish; Surface Finish; Top Layer; Signal; GTL; Prepreg; Dielectric; Int1 (GND); Internal Plane GP1; Core; Core-035; Int2 (Sign); Int3 (Sign); Int4 (PWR); Internal Plane GP2; Bottom Layer; GBL; Bottom Surface Finish 0.02mm; Surface Material Bottom Solder; GBS; Bottom Overlay; GBO; Total thickness: 1.64mm

Layer Stack Legend

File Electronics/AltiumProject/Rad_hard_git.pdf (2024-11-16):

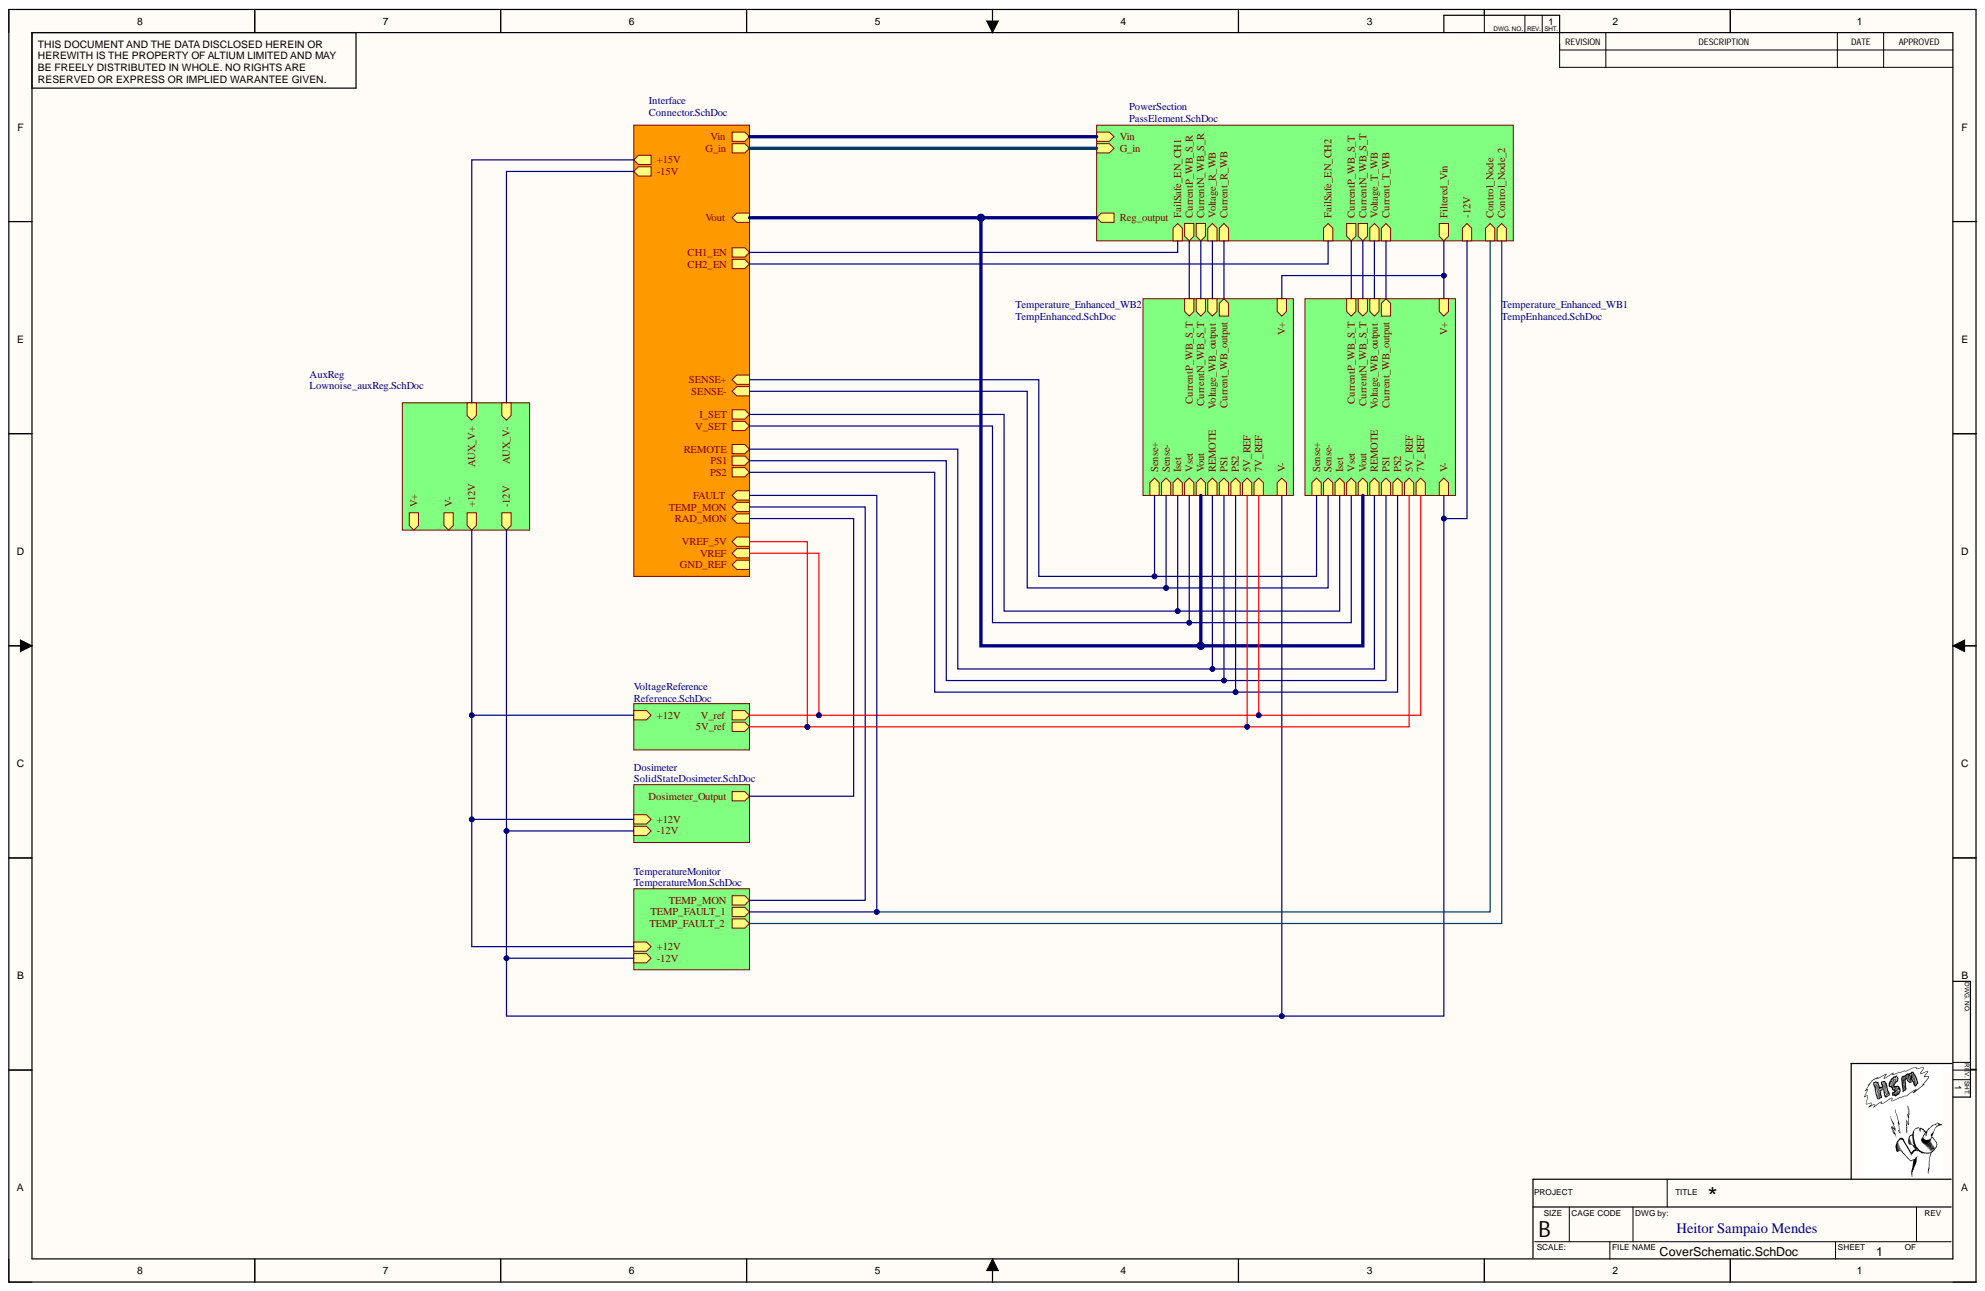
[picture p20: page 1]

8 | 7 | 6 | 5 | 4 | 3 | DWG. NO. | REV. | 1 SHT. | 2 | 1

THIS DOCUMENT AND THE DATA DISCLOSED HEREIN OR HEREWITH IS THE PROPERTY OF ALTIUM LIMITED AND MAY BE FREELY DISTRIBUTED IN WHOLE. NO RIGHTS ARE RESERVED OR EXPRESS OR IMPLIED WARANTEE GIVEN. | Interface PowerSection Connector.SchDoc PassElement.SchDoc | REVISION | DESCRIPTION | DATE | APPROVED

REV. SHT. DWG. NO.

PROJECT | TITLE *

SIZE | CAGE CODE | DWG by: Heitor Sampaio Mendes | REV

SCALE: | FILE NAME | SHEET OF

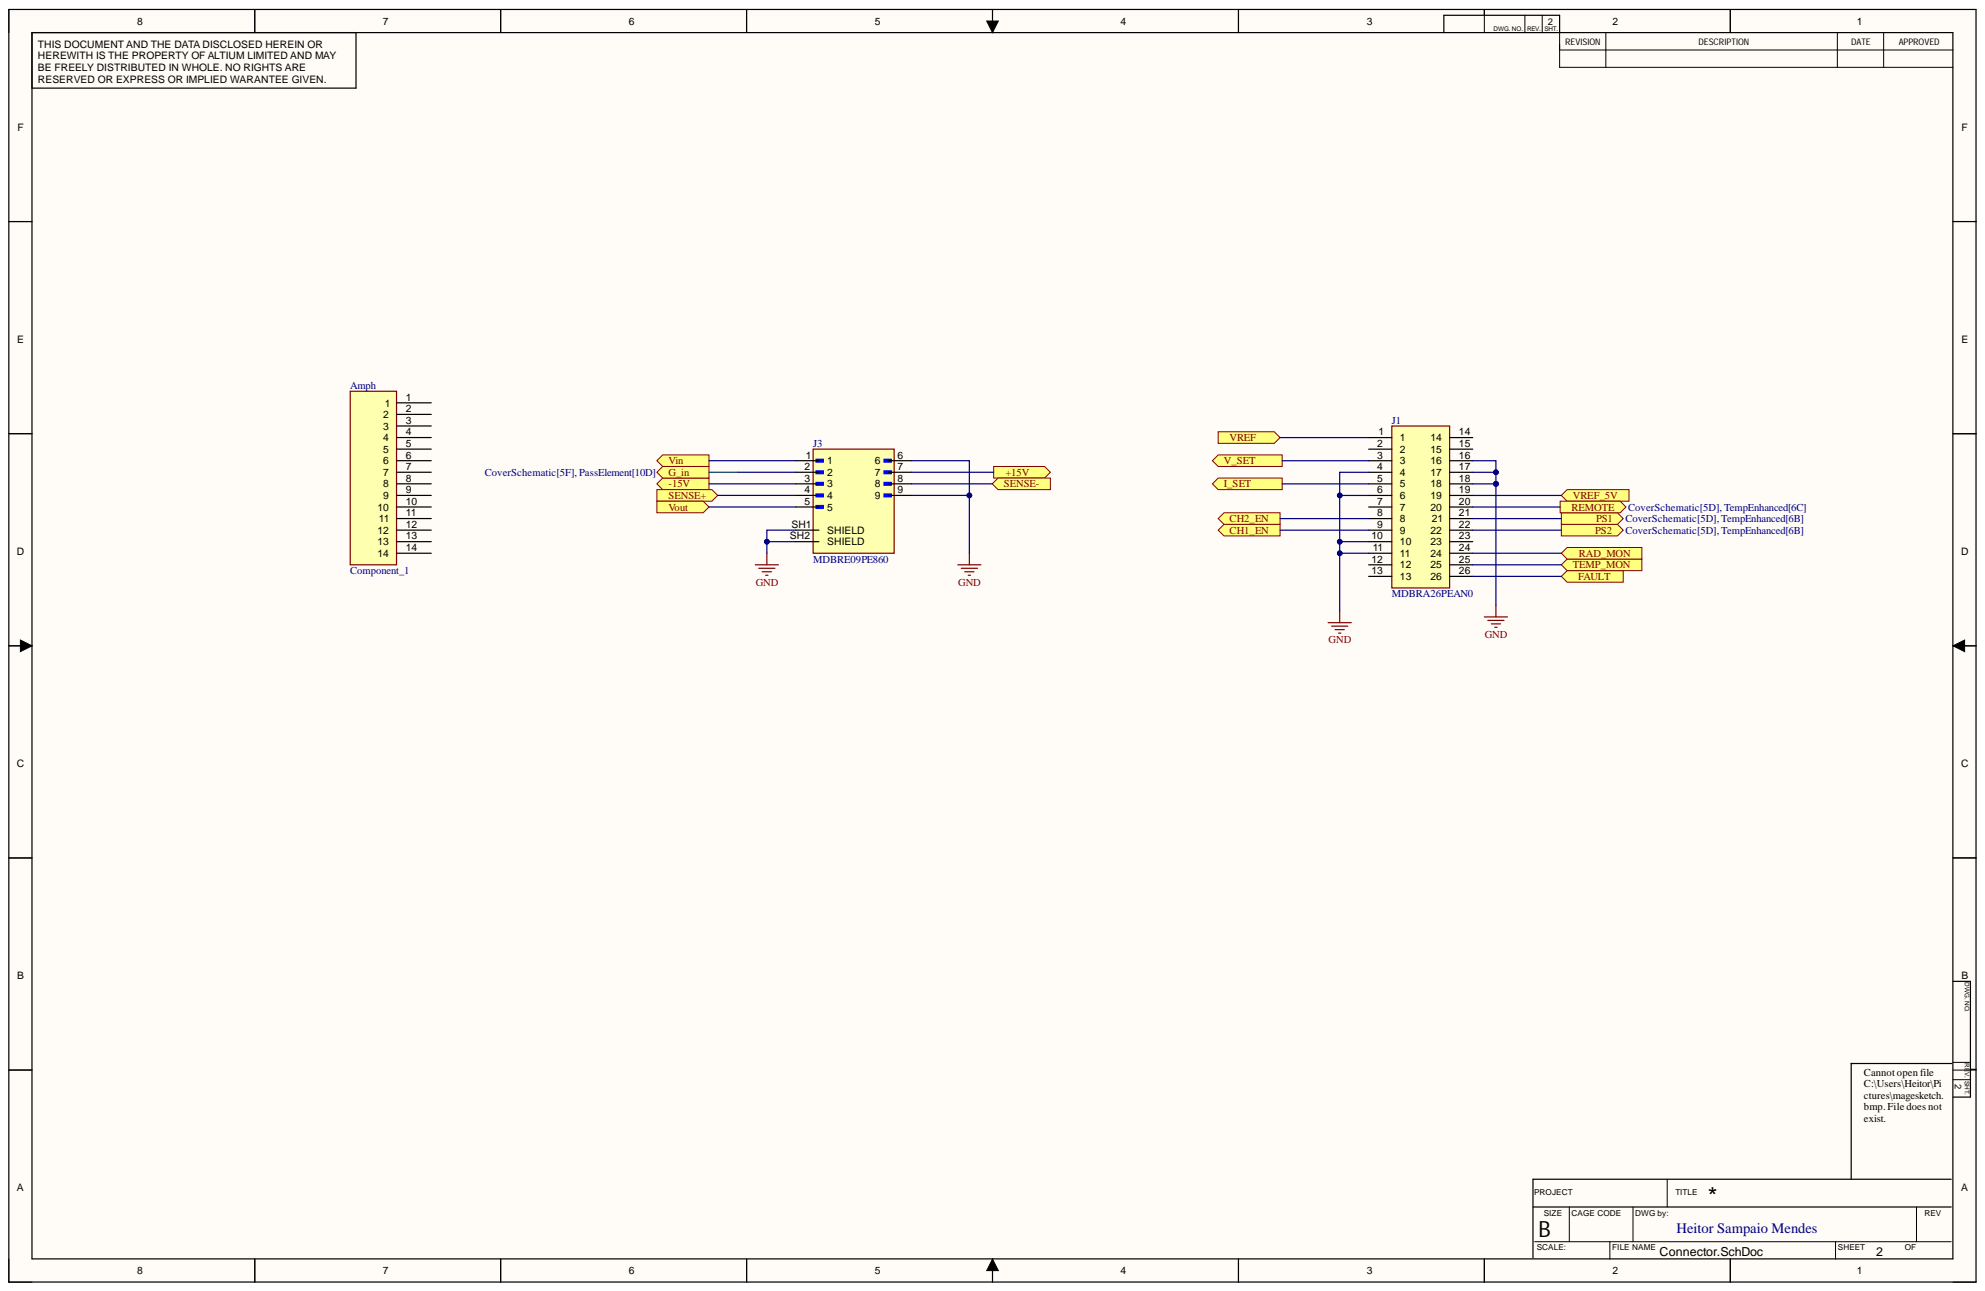
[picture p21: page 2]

DWG. NO | . REV | 2 . SHT | .

TH IS D O C UMEN T AN D THE D ATA D ISCLOSED HEREI N O R HEREWITH IS THE PR OPERTY OF ALTI UM LIMITED AN D MAY BE FREEL Y D ISTR IBUTED I N WH OLE. N O R I G HTS AR E RESERVED O R EXPRESS O R IMPLIED WARANTEE G IVEN . | Amp h | RE VISION | DE SCRIPTION | DATE | A P PROV E D

REV. SHT. DWG. NO.

PROJEC T | T I TLE *

SI Z E | CAGE COD E | D WG by : Heitor Sampaio Mendes | REV

SCALE: | F ILE NAM E h D o c | SHEET 2 OF

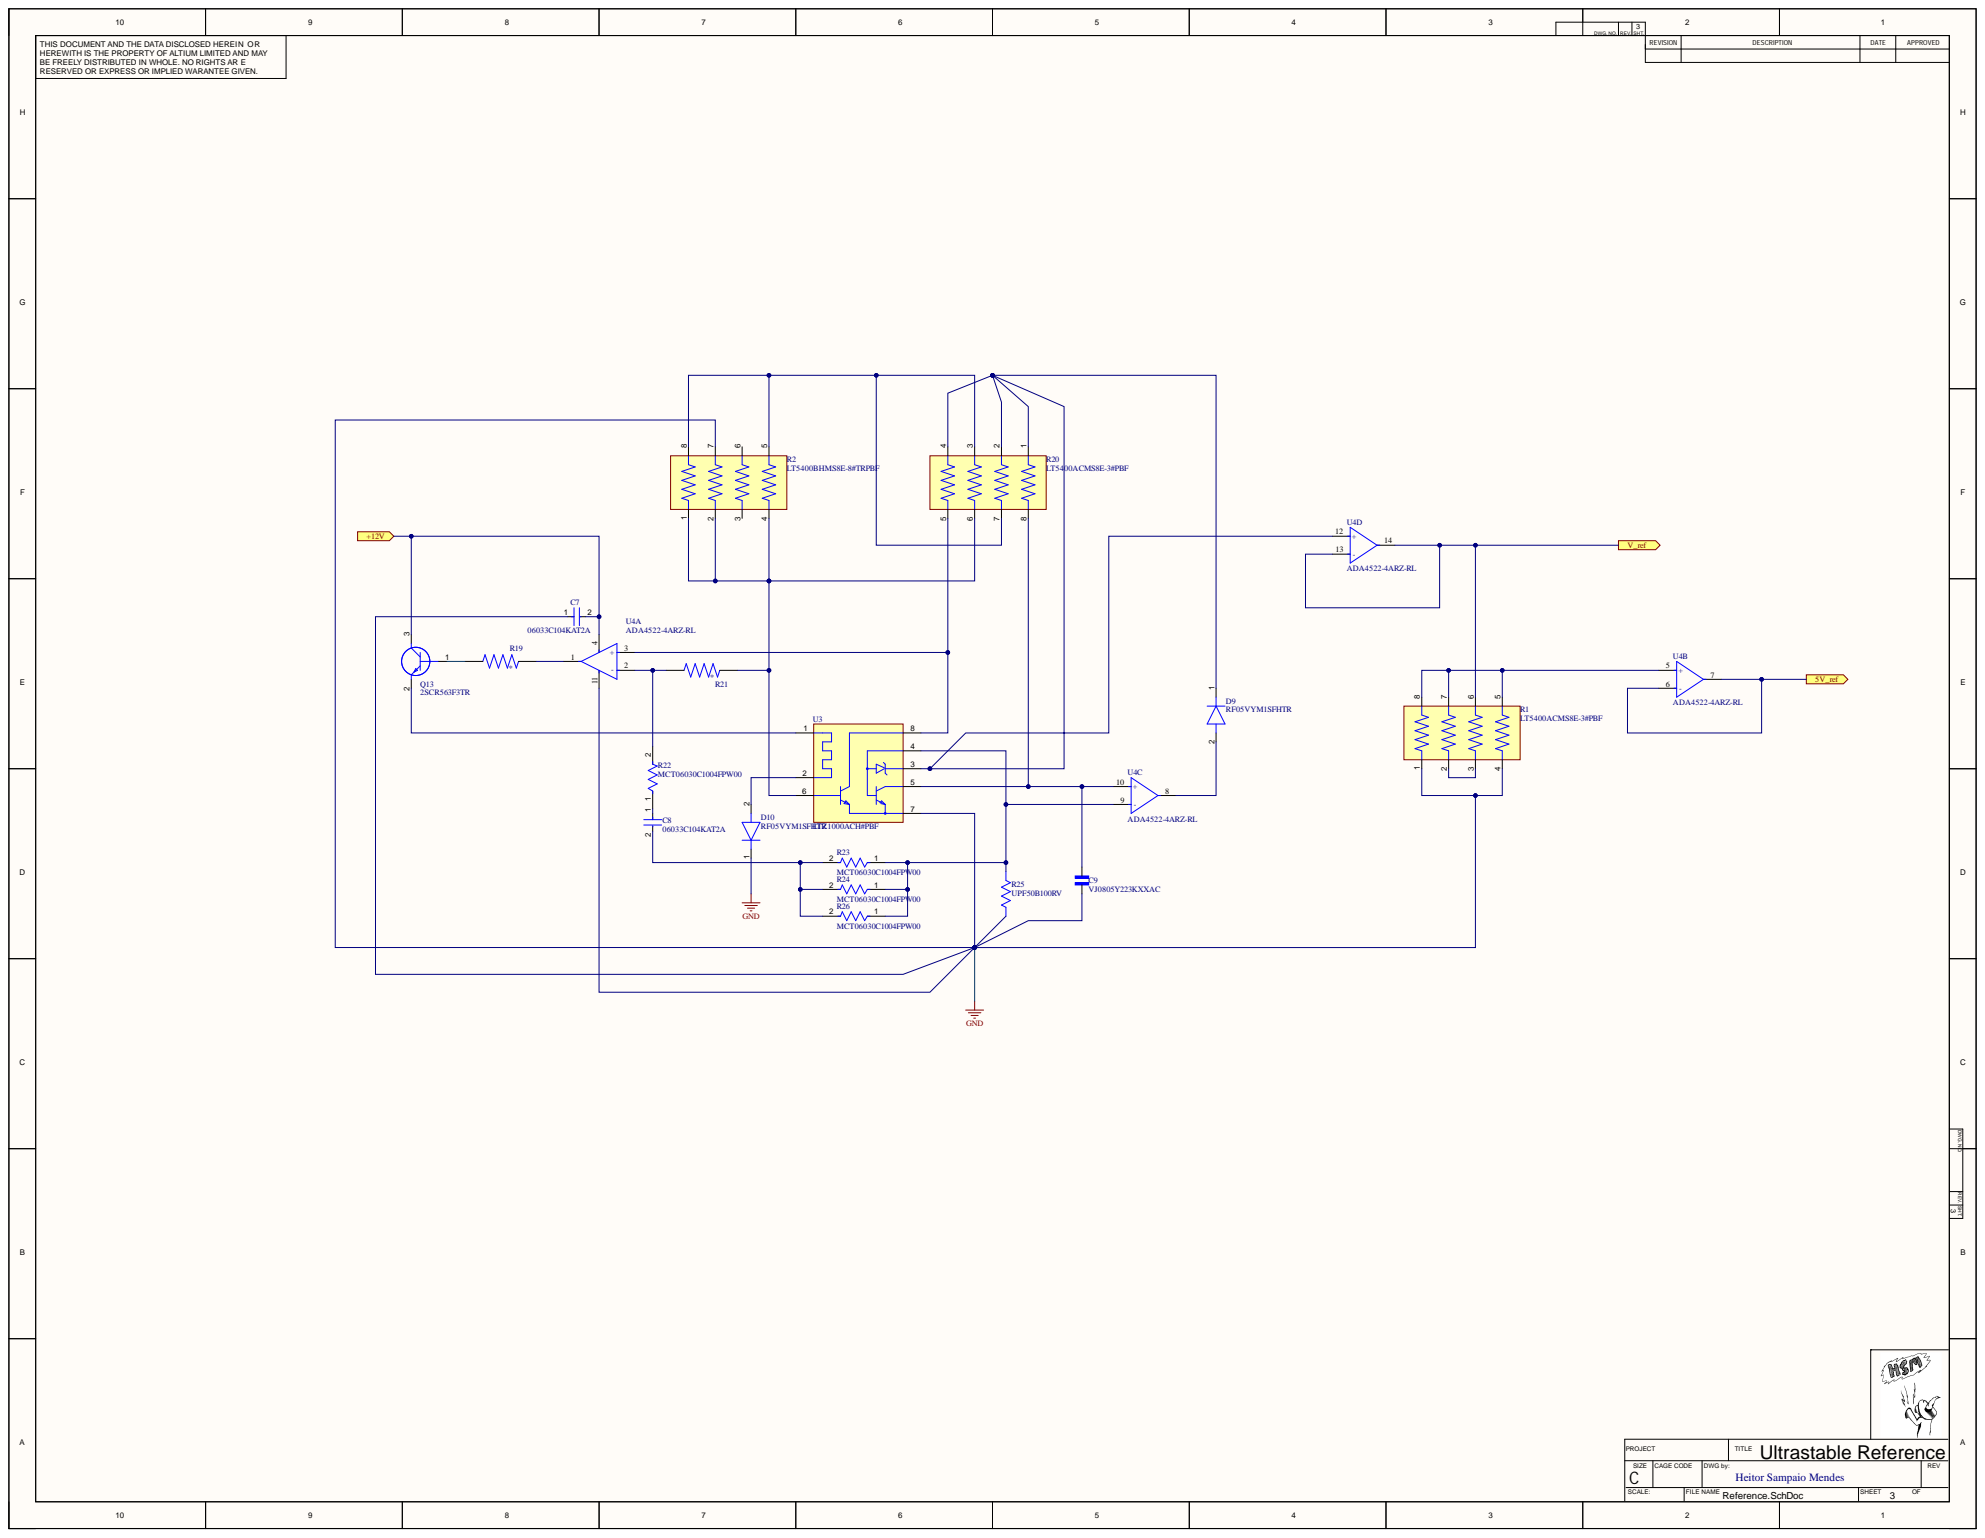
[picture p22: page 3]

THIS DOCUM ENT AND THE DATA DISCLOS ED HEREIN OR HERE WITH IS THE PROP ERTY OF A LTIUM LIMITED AND M AY B E FRE E LY DISTRIBUTED IN WHOL E. NO RIGHTS ARE RE S ERV ED OR E X PRE S S OR IM P LIED W ARANTE E GIV EN. | | R E V I S I O N | D E S C R I P T I O N | D A T E | A P P R O V E D

DWG . N O | . R E V | . S H | T.

AREV. SHT. DWG. NO.

PRO JECT | TITL E Ultrastable Reference

SIZE | CAGE CODE | DWG b y : Heitor S amp aio Me n d e s | REV

SCALE: | FILE NAM E c h D o c | SHEET O F

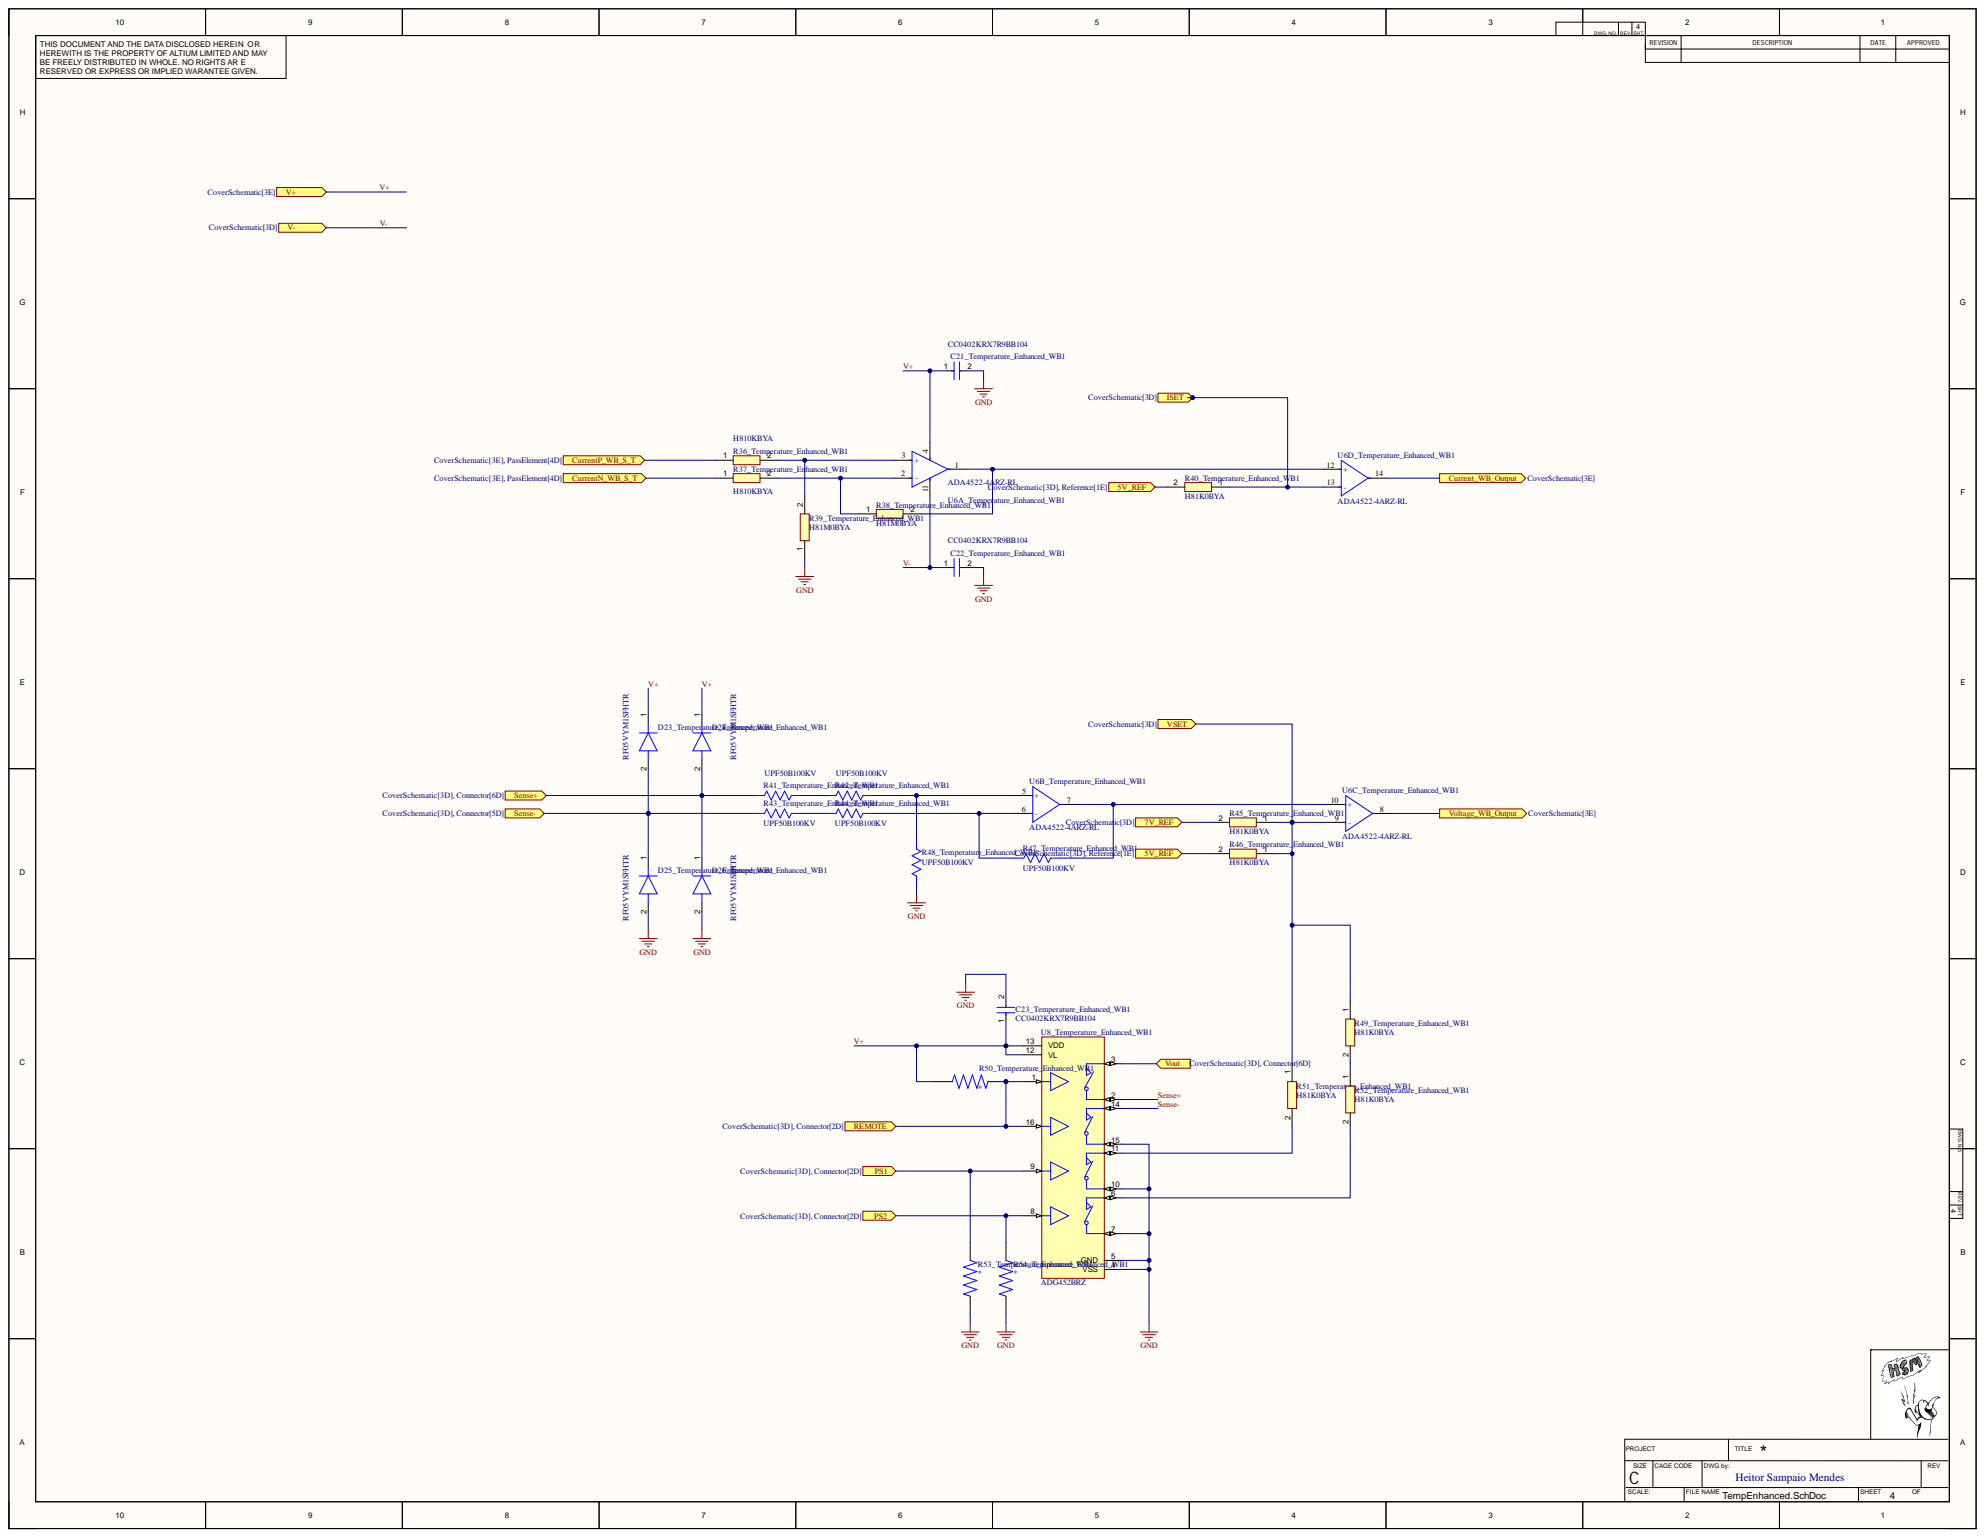
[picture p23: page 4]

THIS DOCUMENT AND THE DATA DISCLOSED HEREIN OR HEREWITH IS THE PROPERTY OF ALTIUM LIMITED AND MAY BE FREELY DISTRIBUTED IN WHOLE. NO RIGHTS ARE RESERVED OR EXPRESS OR IMPLIED WARANTEE GIVEN. | CC0402KRX7R9BB104 C21_Temperature_Enhanced_WB1 | REVISION | DESCRIPTION | DATE | APPROVED

DWG. NO. | REV. | SHT.

REV. SHT. DWG. NO.

PROJECT | TITLE *

SIZE | | DWG by: Heitor Sampaio Mendes

FILE NAME | SHEET OF

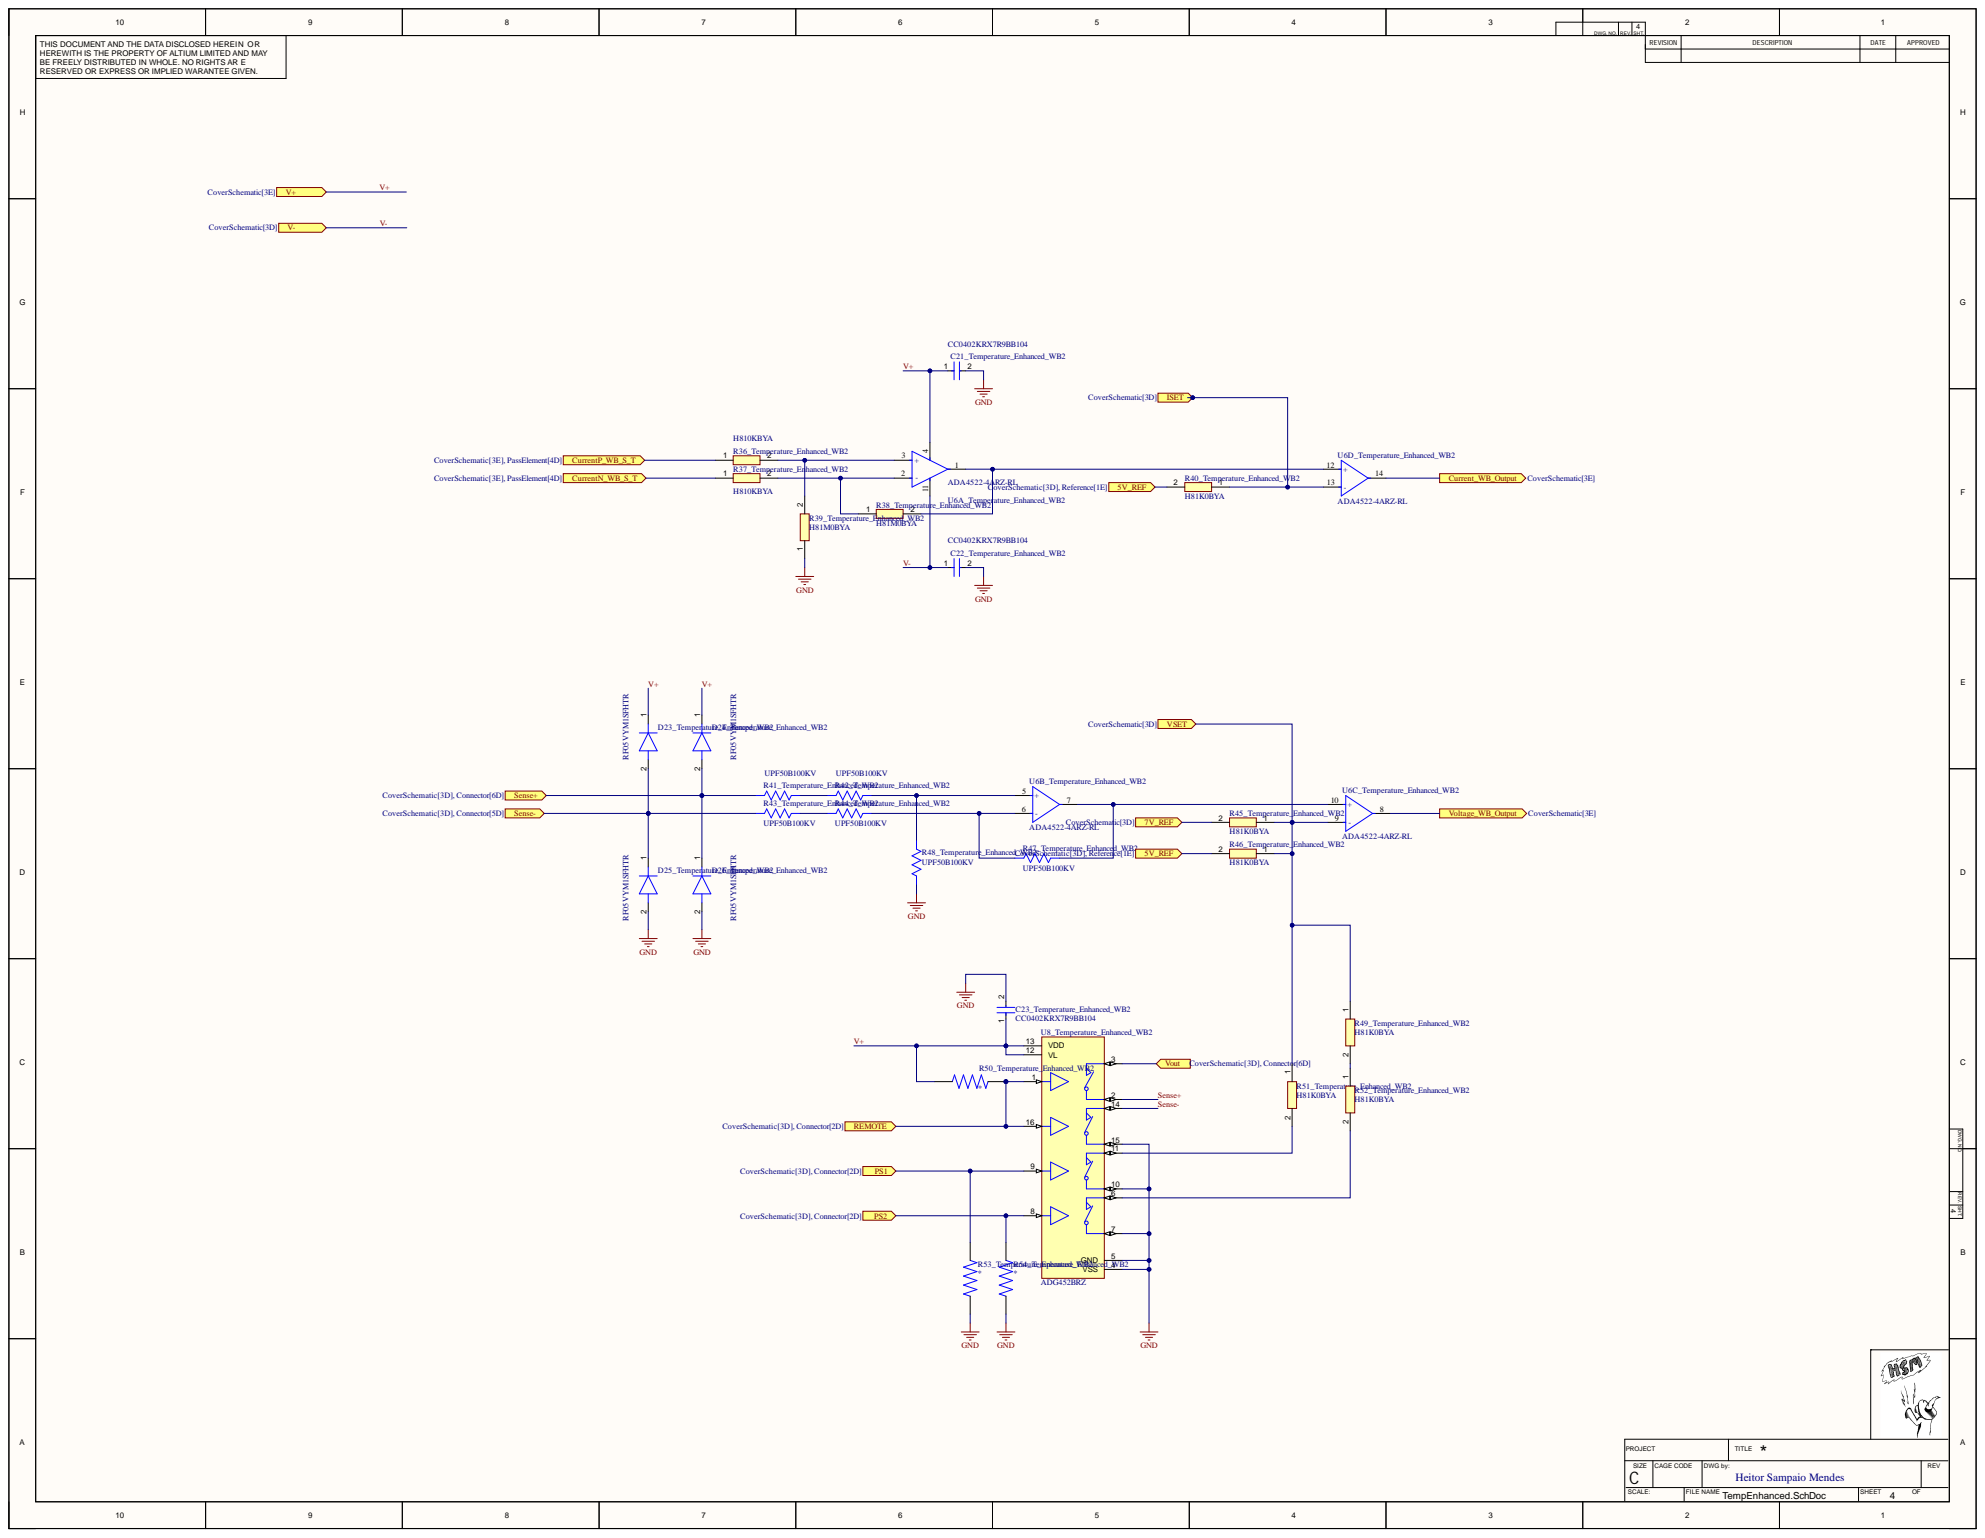
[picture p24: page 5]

THIS DOCUMENT AND THE DATA DISCLOSED HEREIN OR HEREWITH IS THE PROPERTY OF ALTIUM LIMITED AND MAY BE FREELY DISTRIBUTED IN WHOLE. NO RIGHTS ARE RESERVED OR EXPRESS OR IMPLIED WARANTEE GIVEN. | CC0402KRX7R9BB104 C21_Temperature_Enhanced_WB2 | REVISION | DESCRIPTION | DATE | APPROVED

DWG. NO. | REV. | SHT.

REV. SHT. DWG. NO.

PROJECT | TITLE *

SIZE | | DWG by: Heitor Sampaio Mendes

FILE NAME | SHEET OF

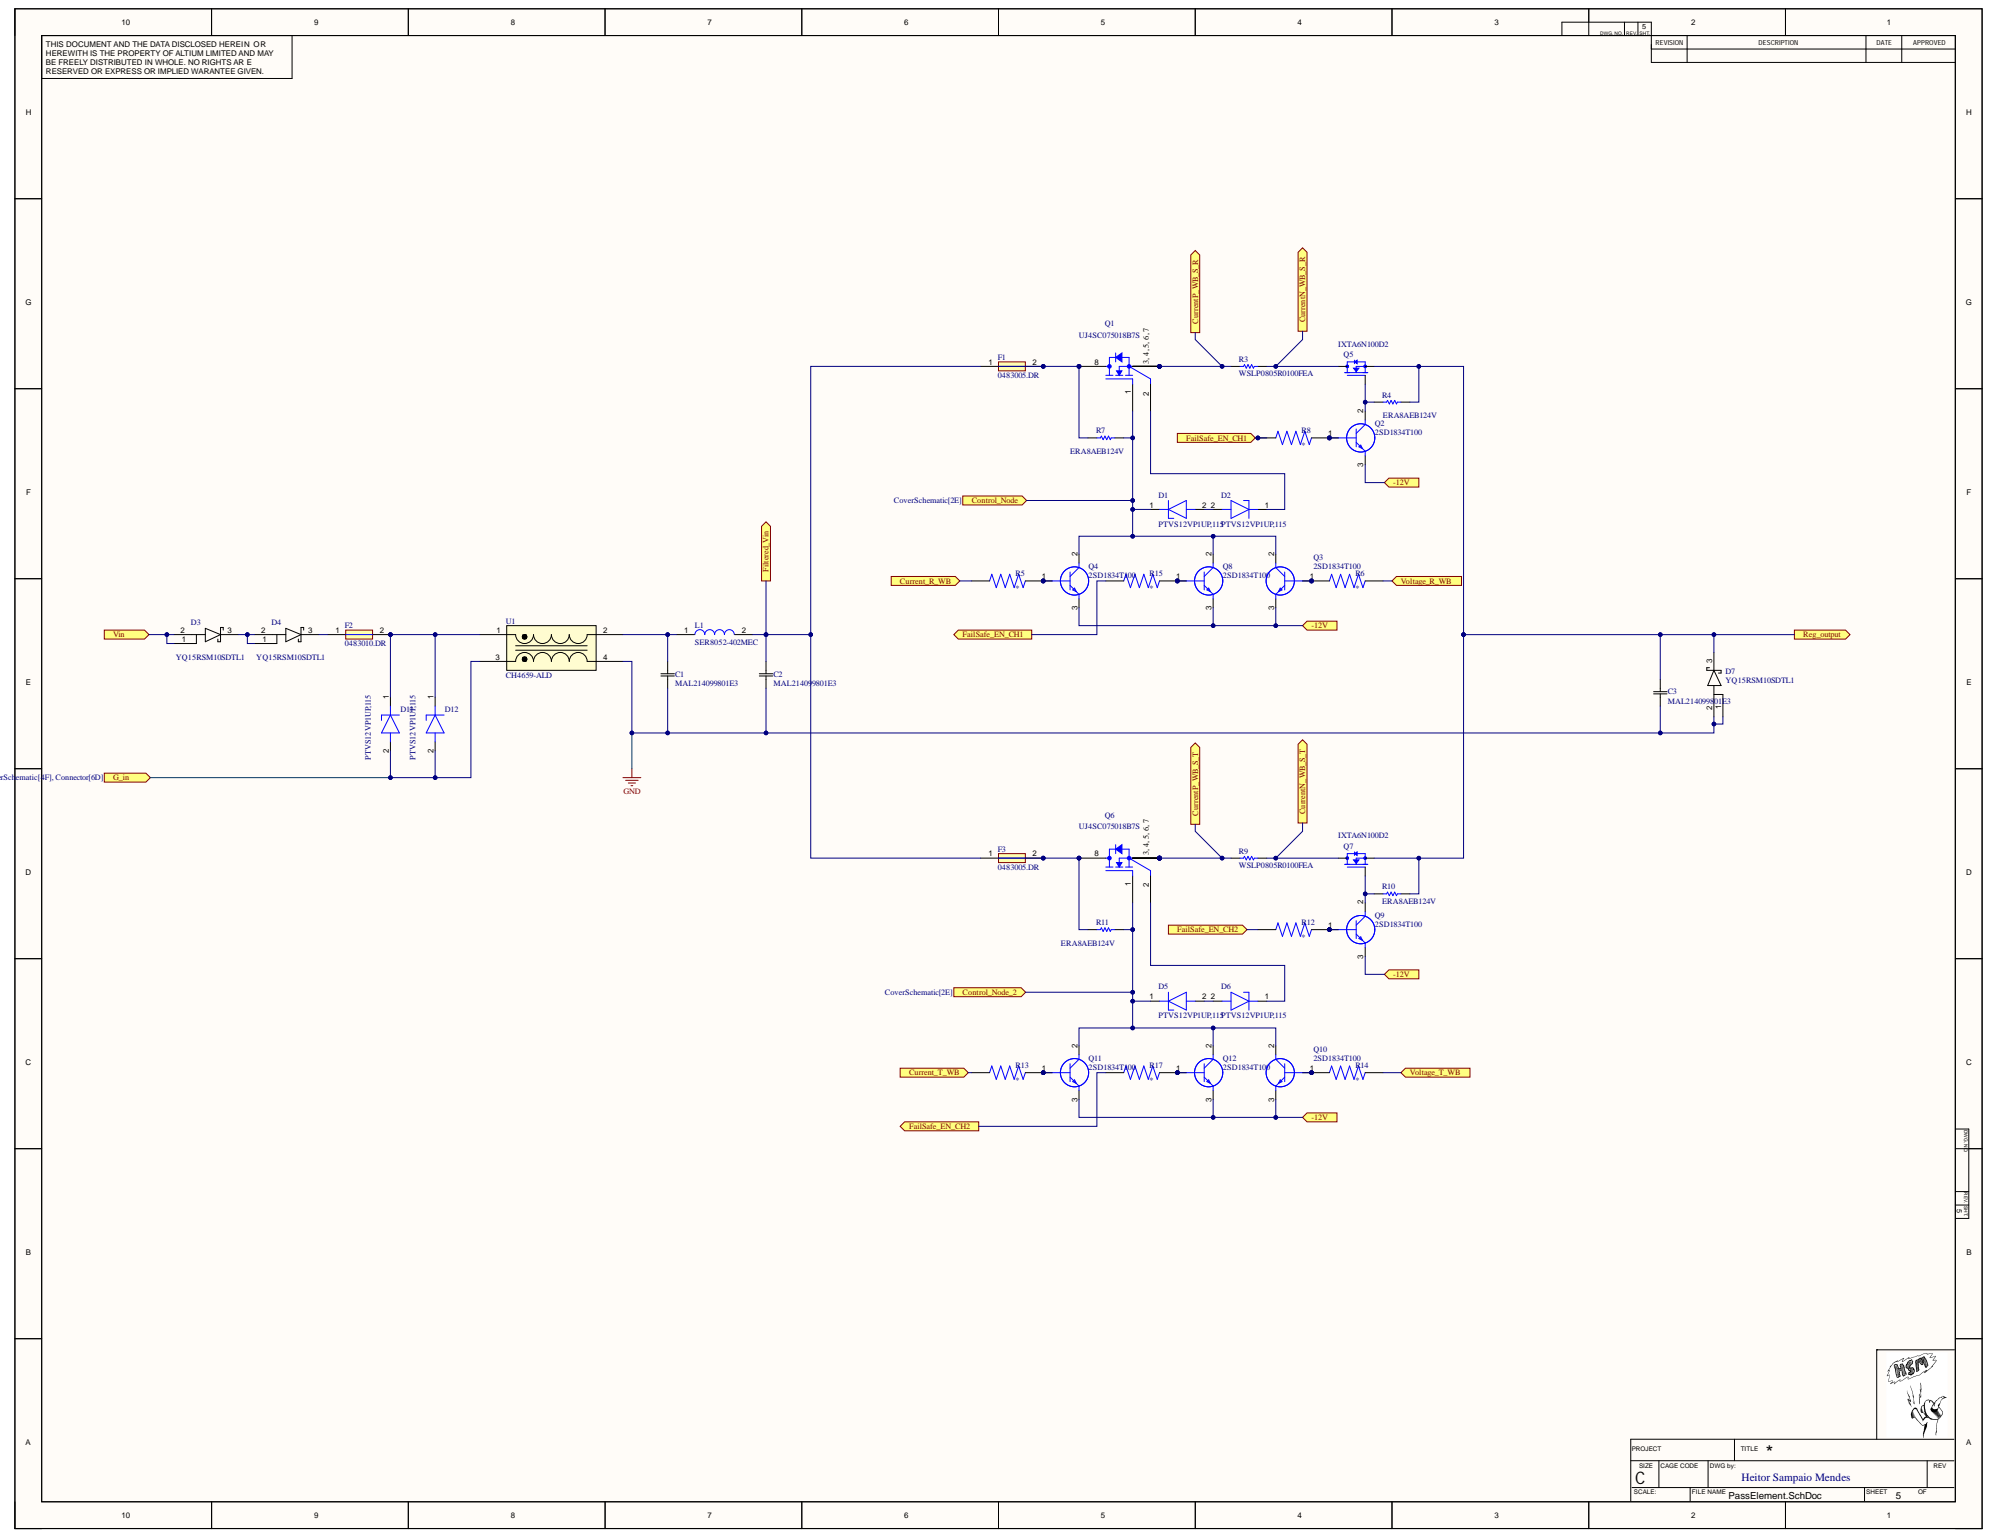
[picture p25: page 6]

THIS DOCUM ENT AND THE DATA DISCLOS ED HEREIN OR HERE WITH IS THE PROP ERTY OF A LTIUM LIMITED AND M AY B E FRE E LY DISTRIBUTED IN WHOL E. NO RIGHTS ARE RE S ERV ED OR E X PRE S S OR IM P LIED W ARANTE E GIV EN. | Q 1 U J 4SC0 7 5 0 1 8 B 7 IX TA 6 N 1 0 0 D 2 | R E V I S I O N | D E S C R I P T I O N | D A T E | A P P R O V E D

DWG . N O | . R E V | . S H | T.

AREV. SHT. DWG. NO.

PRO JECT | TITL E *
SIZE C | | DWG b y : Heitor S amp aio Me n d e s

FILE NAM E PassElement.Sch D o c | SHEET O F

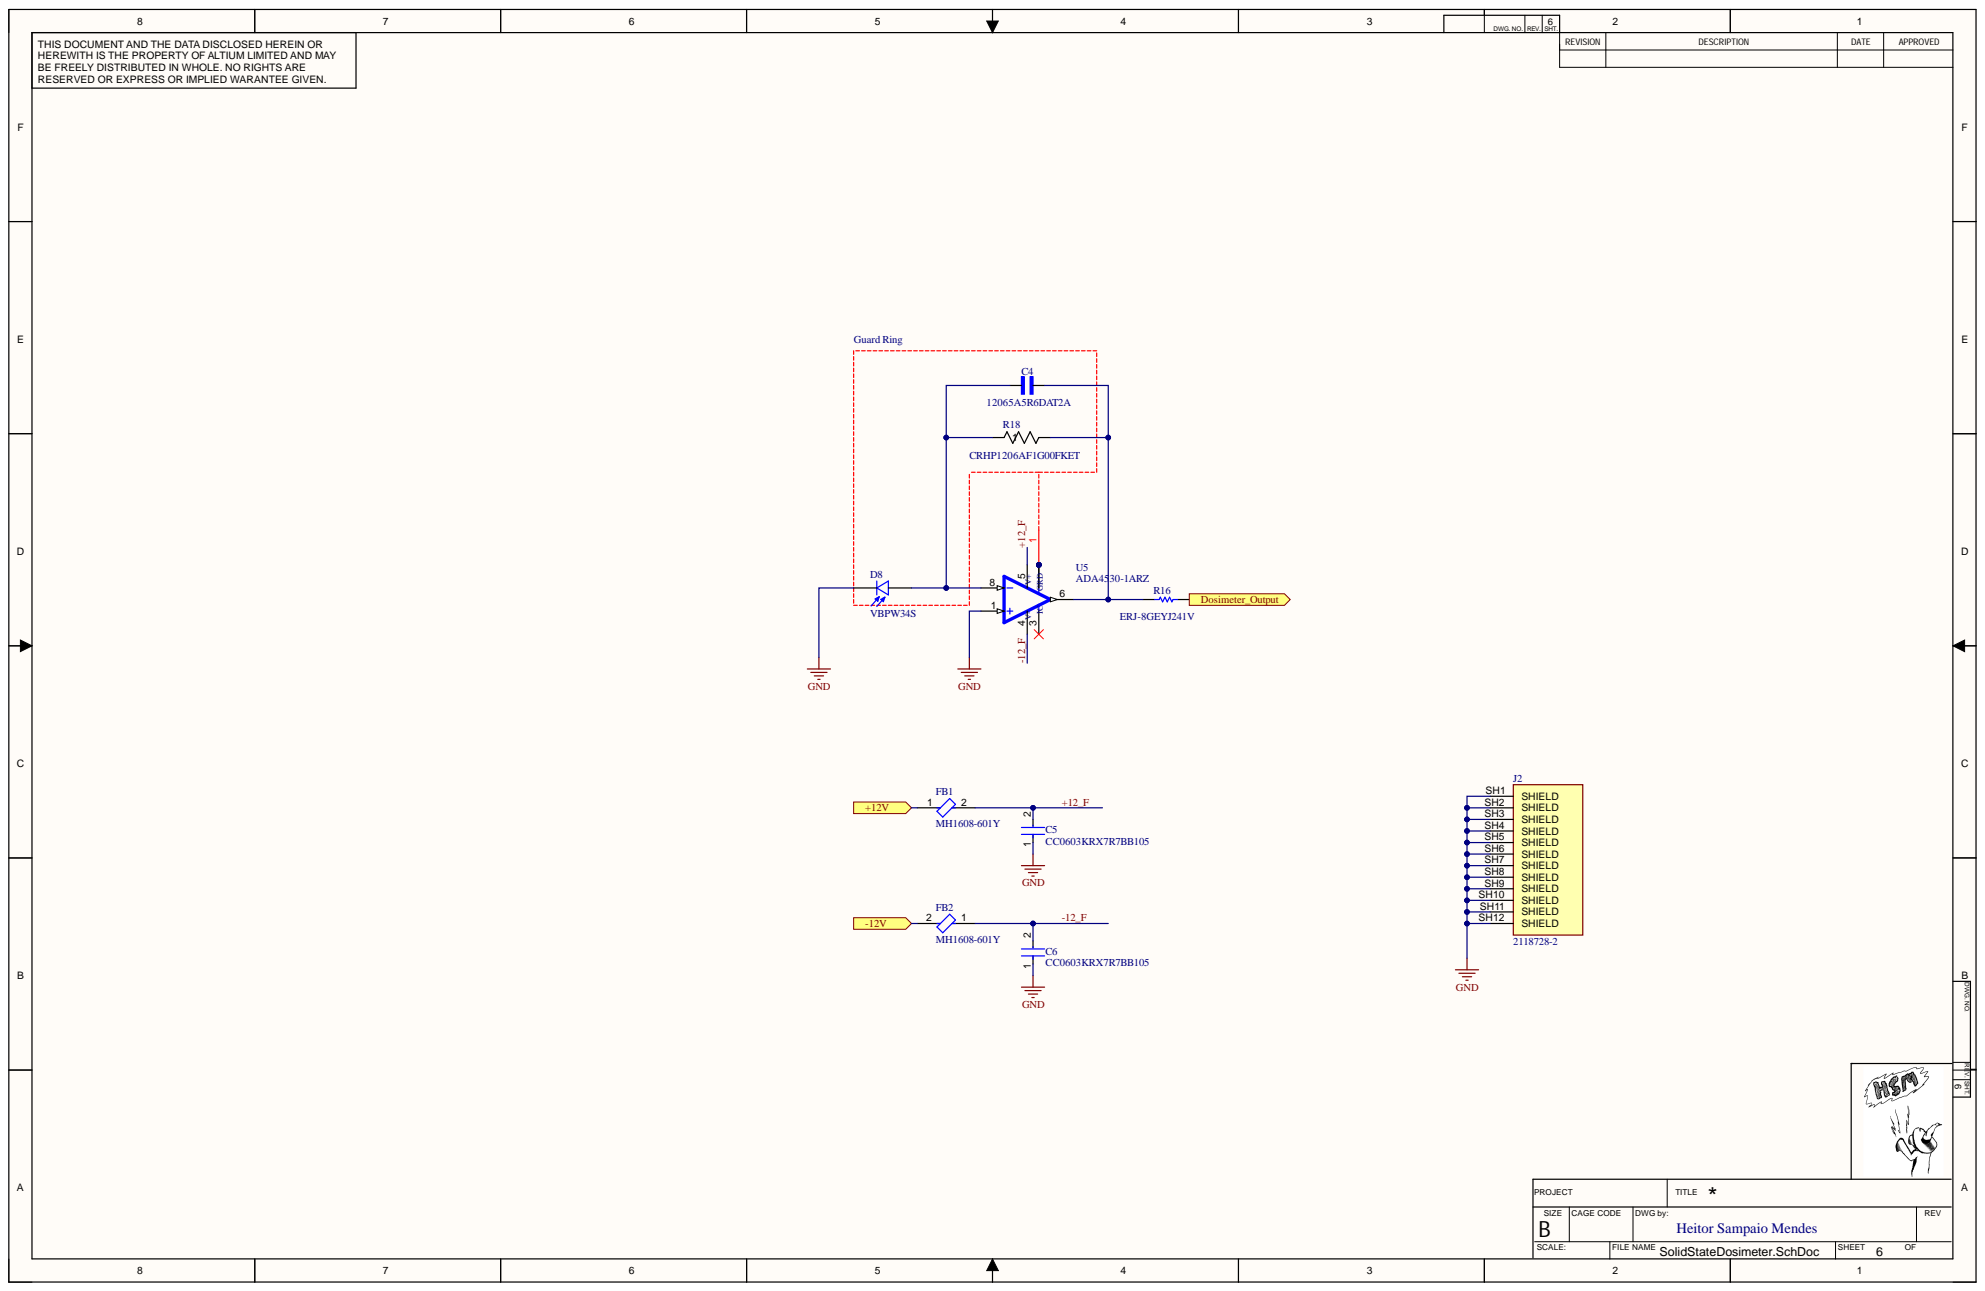
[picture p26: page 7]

8 | 7 | 6 | 5 | 4 | 3 | DWG. NO. | REV. | 6 SHT. | 2 | 1

THIS DOCUMENT AND THE DATA DISCLOSED HEREIN OR HEREWITH IS THE PROPERTY OF ALTIUM LIMITED AND MAY BE FREELY DISTRIBUTED IN WHOLE. NO RIGHTS ARE RESERVED OR EXPRESS OR IMPLIED WARANTEE GIVEN. | | REVISION | DESCRIPTION | DATE | APPROVED

REV. SHT. DWG. NO.

PROJECT | TITLE *

SIZE | CAGE CODE | DWG by: Heitor Sampaio Mendes | REV

SCALE: | FILE NAME | SHEET OF

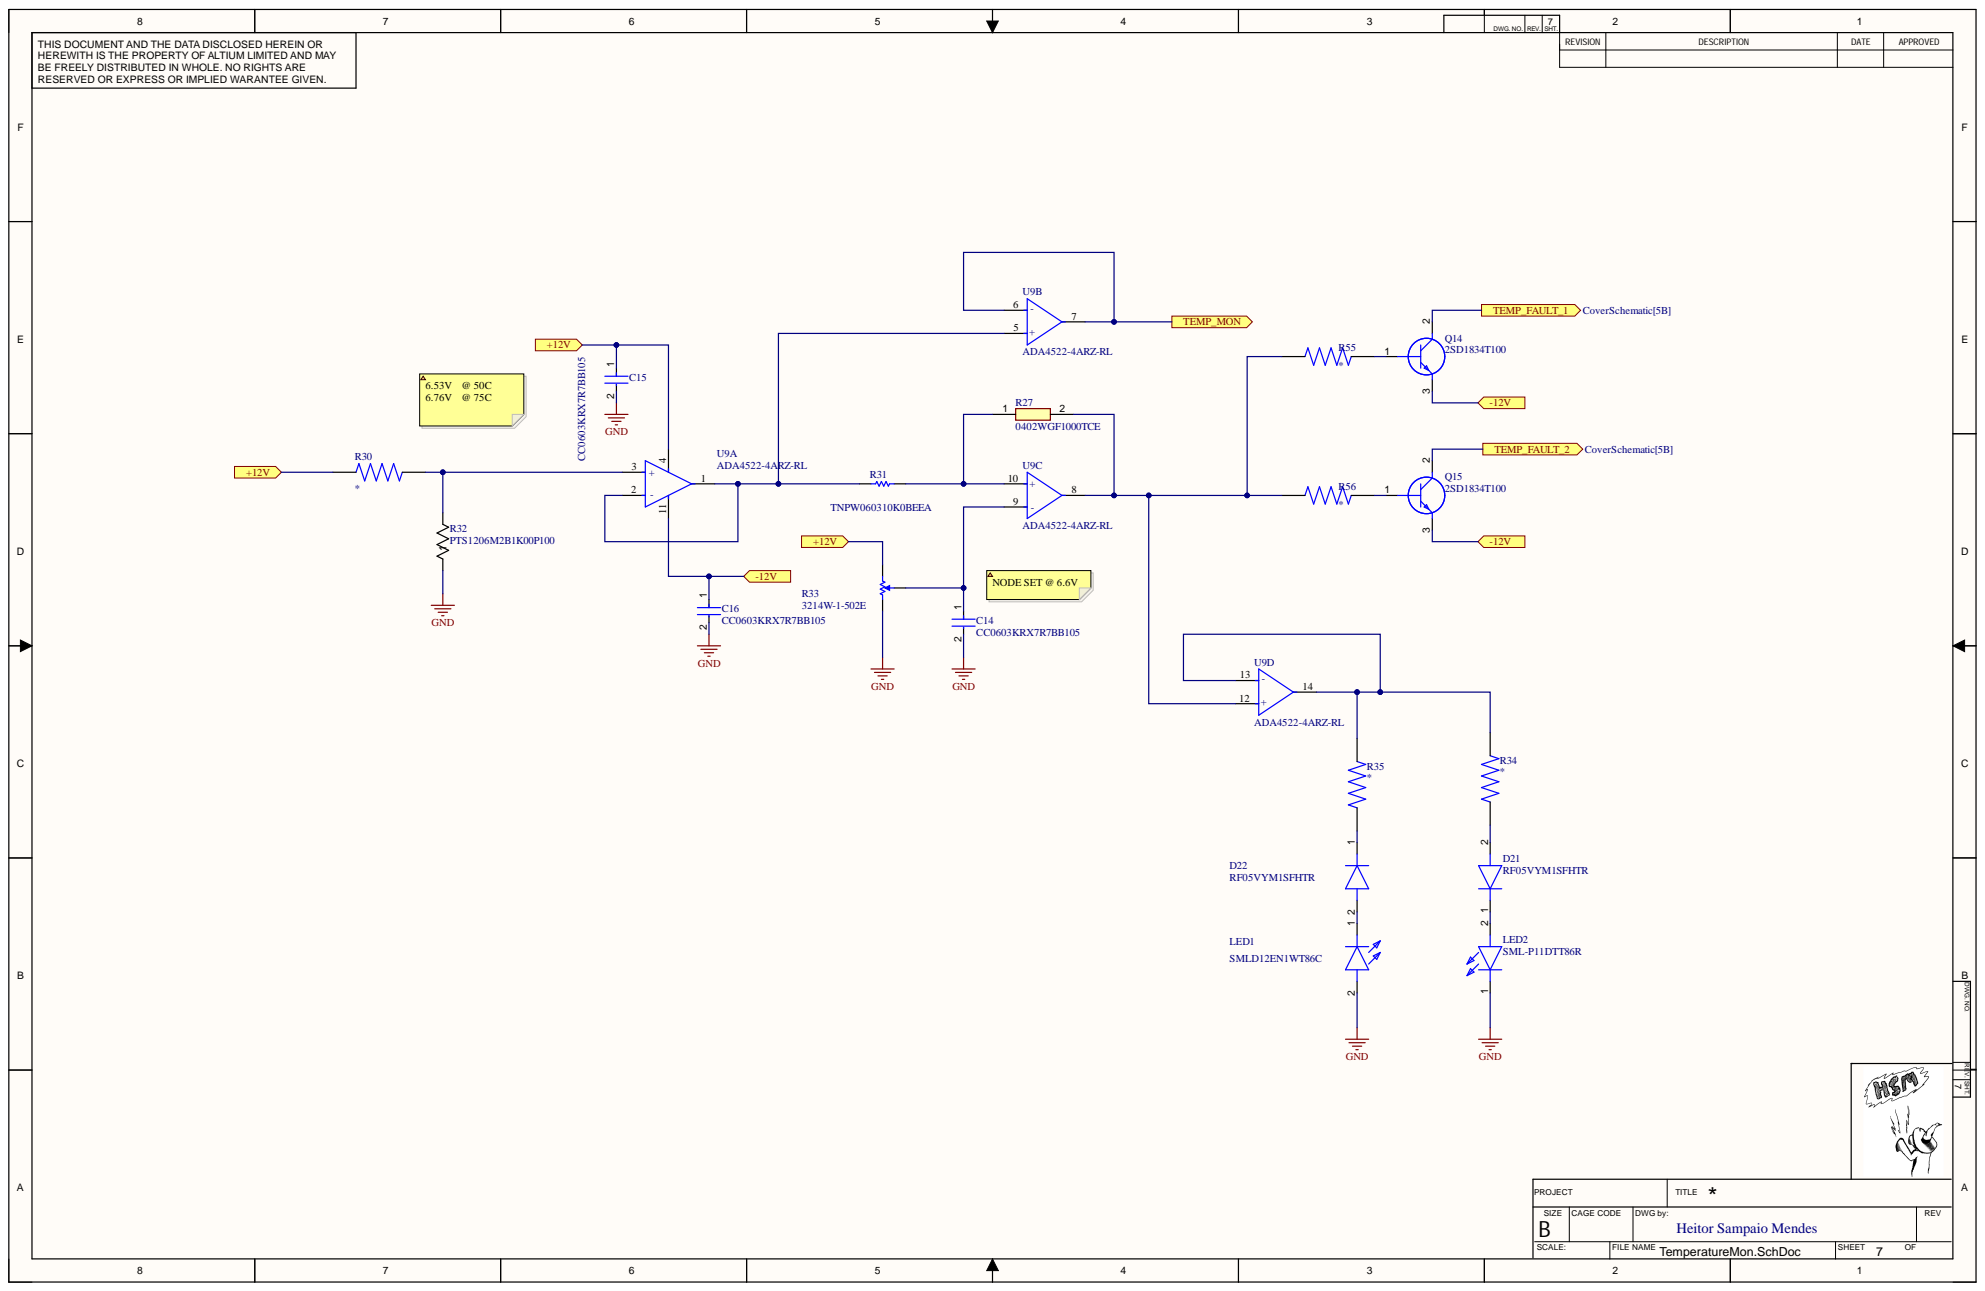
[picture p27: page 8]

8 | 7 | 6 | 5 | 4 | 3 | DWG. NO. | REV. | 7 SHT. | 2 | 1

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

REV. SHT. DWG. NO.

PROJECT | TITLE *

SIZE | CAGE CODE | DWG by: Heitor Sampaio Mendes | REV

SCALE: | FILE NAME | SHEET OF

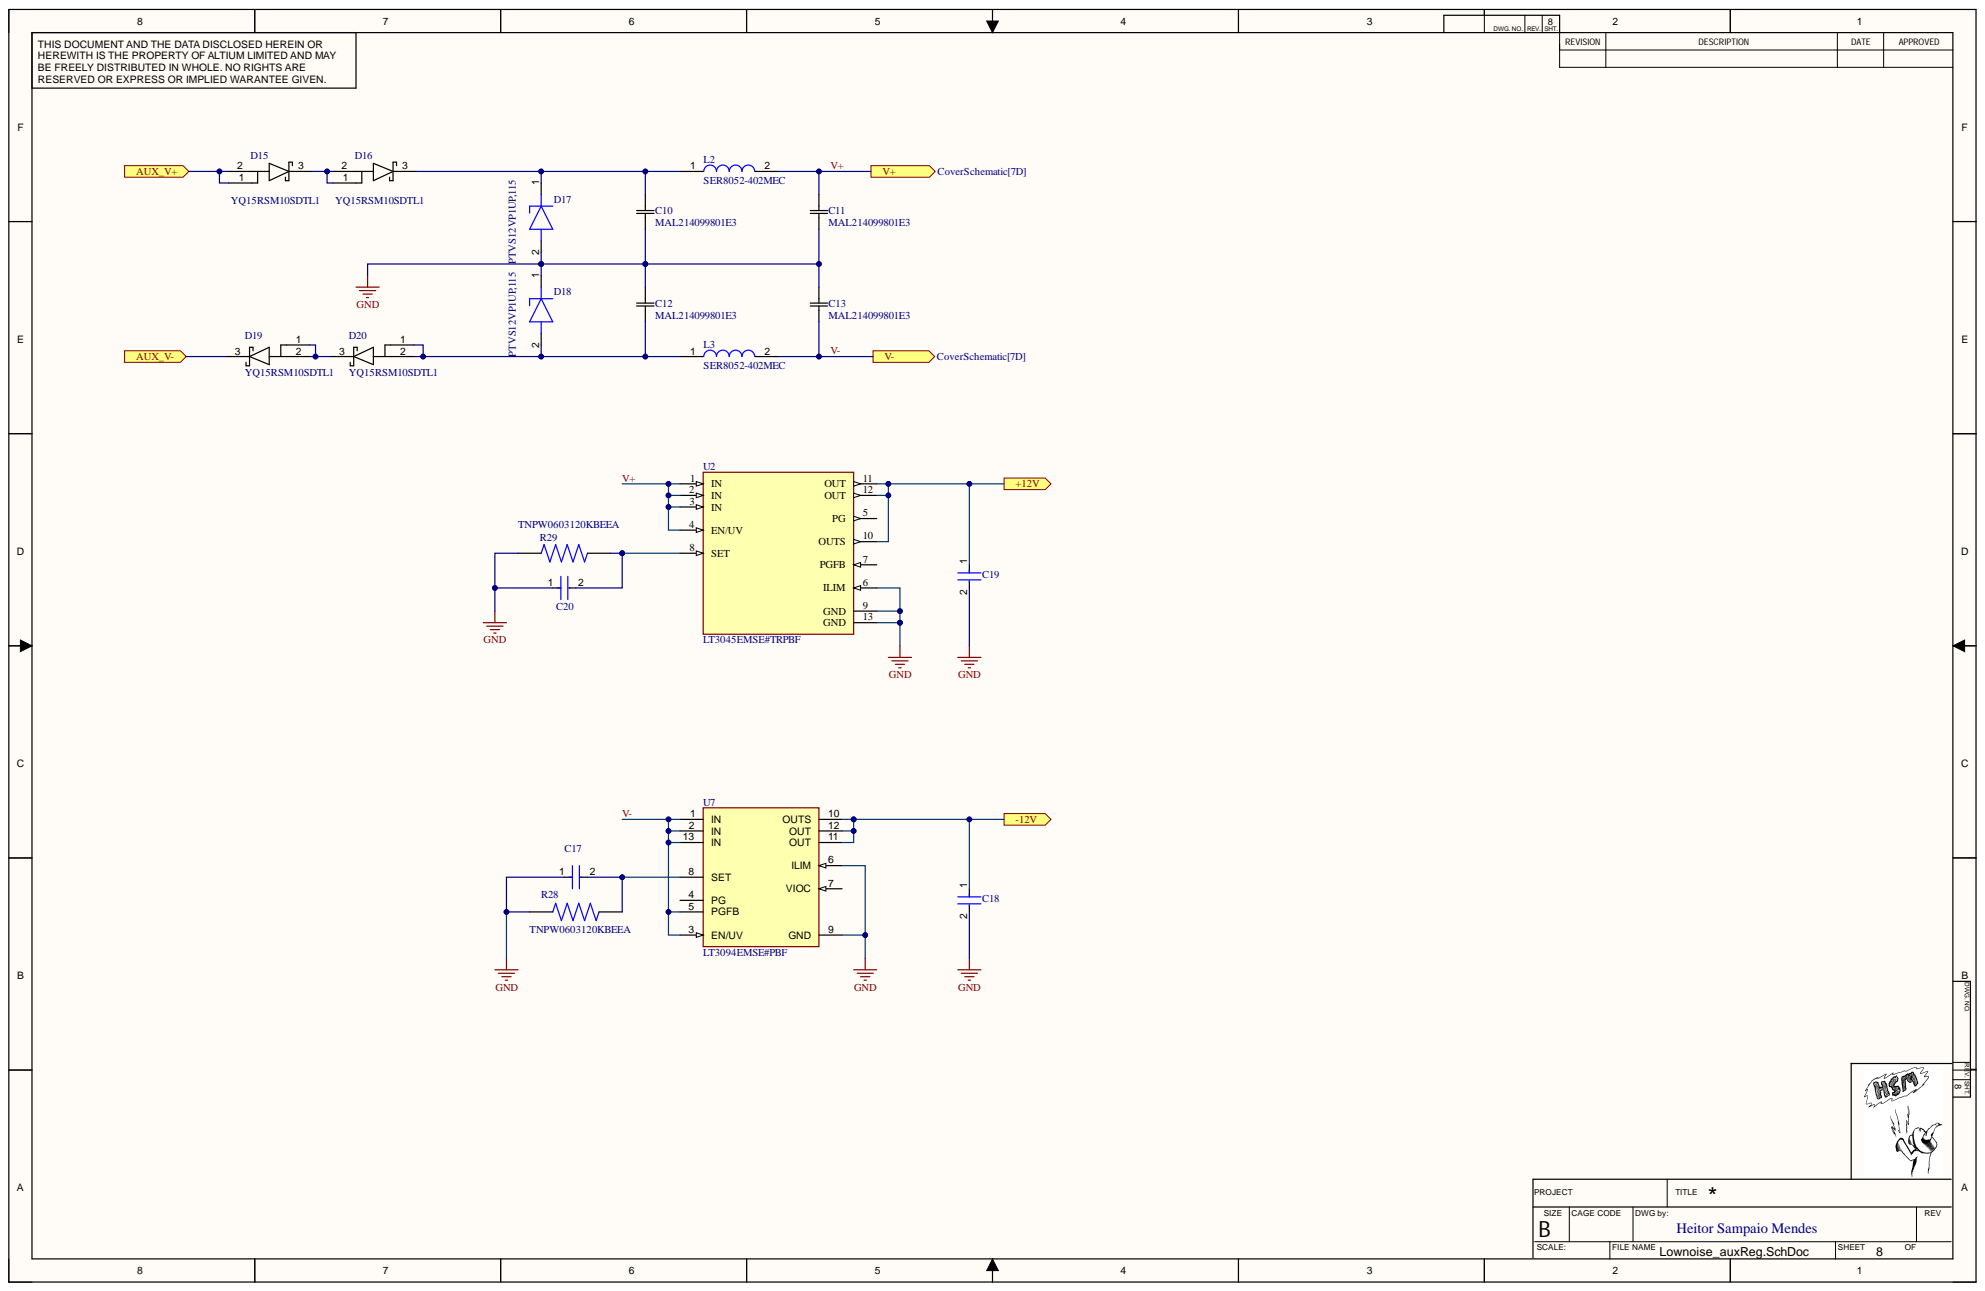
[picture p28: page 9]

8 | 7 | 6 | 5 | 4 | 3 | DWG. NO. | REV. | 8 SHT. | 2 | 1

THIS DOCUMENT AND THE DATA DISCLOSED HEREIN OR HEREWITH IS THE PROPERTY OF ALTIUM LIMITED AND MAY BE FREELY DISTRIBUTED IN WHOLE. NO RIGHTS ARE RESERVED OR EXPRESS OR IMPLIED WARANTEE GIVEN. | D16 C11 C13 | REVISION | DESCRIPTION | DATE | APPROVED

SET 8

REV. SHT. DWG. NO.

PROJECT | TITLE *

SIZE | CAGE CODE | DWG by: Heitor Sampaio Mendes | REV

SCALE: | FILE NAME | SHEET OF

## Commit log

2024-10-15 Pass_element----resistors and caps to set the comercial values SSD-- amp+ diode Removed aux con-AMPH
    [ADA4530-1ARZ.PcbLib, ADA4530-1ARZ.SchLib, AuxConnector.SchDoc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]
2024-10-16 samtec_Lib innit
    [PcbLib1.PcbLib, Rad_hard_git.PrjPcb, SolidStateDosimeter.SchDoc]
2024-10-17 Dosimeter done, pass elements almost ( still lacks passives ), samtec connector done, INT LIB versioning
    [12065A5R6DAT2A.PcbLib, 12065A5R6DAT2A.SchLib, ACRK-16-01-G-T-B1-M-1.PcbLib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]
2024-10-17 fucked up shield model
    [2118728-2.PcbLib, 2118728-2.SchLib, Rad_hard_git.PrjPcb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]
2024-10-17 started on cover + fixed shielding
    [2118728-2.PcbLib, CoverSchematic.SchDoc, PassElement.SchDoc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]
2024-10-21 solved resistor ratio for reference
    [Reference.SchDoc]
2024-10-28 TempEnhanced Innit
    [CoverSchematic.SchDoc, Lownoise_auxReg.SchDoc, PassElement.SchDoc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]
2024-11-10 PCB design start
    [Connector.SchDoc, CoverSchematic.SchDoc, Lownoise_auxReg.SchDoc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]
2024-11-26 DRC - pass, testpoints, draftsman pdf, gerbers.
    [Rad_hard_git.PrjPcb, Rad_hard_git.xlsx, Reference.SchDoc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]
2024-11-28 temperature_analysis upload
    [radhard3.step]
